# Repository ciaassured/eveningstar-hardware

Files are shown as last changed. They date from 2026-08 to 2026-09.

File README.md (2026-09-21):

# EveningStar Hardware

<p align="center">
  Rotating 3D render of the EveningStar PCB
</p>

EveningStar is a gateway between a Morningstar MeterBus network and a standard Ethernet/IP network. It connects to the MeterBus port of a Morningstar solar charge controller or other compatible device, making the bus accessible over Ethernet for monitoring, automation, and control.

The hardware is built around an ESP32-C6 and divided into two galvanically isolated sections:

* A MeterBus interface, powered from the connected Morningstar device.
* An ESP32 and Ethernet interface, powered from its own DC input.

This isolation keeps the MeterBus network and the Morningstar device's ground separate from the rest of the system, which prevents ground loops through the MeterBus cable and stops fault currents from flowing across it. The ESP32 side can be powered from the same battery system as the charge controller or from a separate supply, even when the two operate at different voltages.

MeterBus communication is half-duplex and open-drain. The interface includes a Schmitt-trigger receive path and transient-voltage-suppression clamps to improve reliability when cables are routed through electrically noisy environments.

## Specifications

| | |
| --- | --- |
| Processor | ESP32-C6-WROOM-1-N8 module: Wi-Fi 6, Bluetooth LE, and IEEE 802.15.4, with 8 MB flash and an on-board antenna |
| Storage | 256 MB SPI NAND flash (GD5F2GM7) |
| Real-time clock | 32.768 kHz crystal |
| Ethernet | 10/100 Mbit/s, WIZnet W5500 with a hardware TCP/IP stack, RJ45 jack with integrated magnetics |
| MeterBus | RJ11 (6P6C) jack to the Morningstar MeterBus port |
| USB | USB-C to the ESP32-C6's native USB, for flashing, a serial console, and JTAG debugging; it does not power the board |
| Debug | Unpopulated 2.54 mm 2×3 header with serial, reset, and boot pins |
| Power input | 8–40 V DC through a 3.81 mm pluggable terminal block, ESP32 side |
| MeterBus supply | Powered by the Morningstar device through the MeterBus port, up to the 15.5 V Morningstar specifies, MeterBus side |
| Isolation | ISO6721 digital isolator between the two sides, rated 3000 V rms withstand and 450 V rms working voltage (basic isolation, UL 1577); only data crosses it |
| Operating temperature | −30 °C to +85 °C, from component ratings |
| Board size | 81.2 × 71.6 mm |

## Protection

* **Power input:** a 1 A fuse, a series Schottky diode against reverse polarity, and a 40 V TVS diode that clamps surges. The TVS diode sets the 40 V upper limit, well within the 80 V rating of the LMR38020S converter behind it.
* **Brown-out:** the ESP32 is held in reset until the converter reports that the 3.3 V rail is in regulation.
* **MeterBus:** galvanic isolation, since the MeterBus side is powered by the Morningstar device and shares no power or ground with the rest of the board. Its supply has a series Schottky diode against reverse polarity and a 17 V TVS diode, and the data line has a TVS clamp for positive and negative spikes.
* **USB:** ESD protection on the data lines. VBUS is not connected to any power rail, so the board cannot draw power from USB or feed power back into it.
* **Ethernet:** the jack's integrated magnetics transformer-couple the data pairs, and its shield is connected to ground only through a 1 nF, 2 kV capacitor, so the Ethernet cable carries no DC ground current.

The ratings above come from component datasheets. The board has not been independently tested or certified for isolation, surge immunity, or its temperature range.

## Installation

* **Power:** connect 8–40 V DC to the terminal block, observing the + and − markings on the bottom of the board. Add a Fuse the positive supply with a 1 A fuse close to the power source, and use wiring rated to carry at least 1 A continuously. This fuse protects the wiring in case of a short circuit. Choose a fuse that is appropriately rated for the system's voltages and currents.
* **MeterBus:** connect the RJ11 jack to the Morningstar device's MeterBus port using a standard straight through cable. The MeterBus side takes its power from that port. The outer two pins on each side of the 6P6C connector are shorted which means it is possible to use a four pin cable, but six pin is recommended.
* **Ethernet:** connect a standard Ethernet cable. The board is not powered over Ethernet. Note that this device does not support Auto-MDIX so a crossover cable may be needed in some cases if the other device also doesn't support auto Auto-MDIX.

> [!WARNING]
> Do not leave USB connected while the system is in service. USB ground is connected directly to the power input's negative terminal, so a connected USB host that is grounded elsewhere creates a second ground path. Current can then flow through the board's unfused ground and the USB cable, which can damage equipment or start a fire. Use USB only for flashing or debugging, and disconnect it afterwards.

## Debugging

### USB

The USB-C port connects straight to the ESP32-C6's native USB; there is no USB-to-serial chip in between. The chip's built-in USB Serial/JTAG controller gives a serial console, flashing, and JTAG debugging over one cable. The controller is part of the chip's hardware and is supported by its ROM bootloader, so it works on a blank module with no bootloader or firmware in flash, and the chip can enter download mode over USB by itself.

Firmware can still make the USB device disappear, by reconfiguring the USB pins, disabling the controller, or entering a sleep mode. If that happens, force the chip into its ROM download mode through the debug header, as below.

Remember that USB is for flashing and debugging only; see the warning under [Installation](#installation).

### Debug header

The unpopulated 2.54 mm 2×3 header, marked DEBUG, breaks out the ESP32's first serial port and its reset and boot pins:

| Pin | Label | Signal |
| --- | --- | --- |
| 1 | RST | ESP32 reset (EN), active low |
| 2 | 3V3 | Board 3.3 V rail, through jumper J_3V3 |
| 3 | TX | ESP32 UART0 transmit; connect to the adapter's receive |
| 4 | GND | Ground |
| 5 | RX | ESP32 UART0 receive; connect to the adapter's transmit |
| 6 | BOOT | ESP32 GPIO9; held low at reset, it enters ROM download mode |

Use it to flash over serial, including the bootloader, or to recover a board whose firmware has disabled native USB: hold BOOT low while releasing RST, and the chip starts in ROM download mode. Programmers that drive both pins can do this automatically.

When using the header, power the board with an external DC supply through its normal power input and on-board converter, and remove jumper J_3V3 so that the programmer's 3.3 V cannot backfeed the converter.

If the converter's power-good signal holds the reset line low while you are trying to flash or debug through the header, remove jumper J_RST as well; it connects the power-good signal to the ESP32's reset line.

J_3V3 and J_RST are 0603 0 Ω resistors beside the header, fitted at assembly and marked on the silkscreen.

## Resources

* Schematics, board drawings, 3D models, renders, and JLCPCB production files for the current hardware revision are attached to the [latest release](https://github.com/ciaassured/eveningstar-hardware/releases/latest).
* To order assembled boards, follow [`docs/jlcpcb_order.md`](docs/jlcpcb_order.md).
* Firmware is maintained separately in the [eveningstar-firmware](https://github.com/ciaassured/eveningstar-firmware) repository.
* The KiCad project and its build, review, and fabrication workflow are documented in [`pcb/README.md`](pcb/README.md).

## Disclaimer

This project is experimental and is not affiliated with or endorsed by Morningstar Corporation.

Use it at your own risk when interfacing with battery and solar equipment.

### AI Assistance

Portions of this project were created or modified using AI-assisted tools. AI-generated suggestions may be incomplete or incorrect and must not be treated as engineering certification.

Before manufacturing or using this hardware, independently review the schematics, PCB layout, component ratings, isolation boundaries, and fabrication outputs. Appropriate electrical, thermal, safety, and regulatory testing must also be performed.

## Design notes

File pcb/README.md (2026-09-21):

# EveningStar PCB

This directory contains the KiCad project for the EveningStar PCB.

## Reproducibility Goal

The PCB should remain openable from this repository in the future, even if
external KiCad libraries, plugin indexes, vendor APIs, or downloaded data
sources disappear or change shape.

The rule of thumb is:

- Project-specific symbols, footprints, and 3D models should be committed under
  `pcb/lib`.
- Third-party libraries that are used by the board should be vendored into this
  repository, not referenced through a local KiCad plugin path.
- External tools are acceptable when they are sufficiently pinned and
  recoverable. KiCad itself is provided through the root Nix flake and locked by
  `flake.lock`.
- KiCad stock symbols are referenced through `KICAD_SYMBOL_DIR`, which is set by
  the Nix tooling to the flake-pinned KiCad package.

If a part needs local customization, copy the symbol, footprint, or model into a
project-owned library and reference that copy.

## Nix Workflow

The root flake owns the lock file and imports the PCB-specific Nix module from
`pcb/nix`. Use the flake from the repository root.

Open a shell with the pinned KiCad version:

```sh
nix develop
```

The dev shell includes KiCad plus the project helper scripts. Inside the shell,
the scripts are available as `eveningstar-*` commands.

Entering the development shell installs or updates the repo's pre-commit hook
for the current clone. It can also be installed explicitly from the shell:

```sh
lefthook install
```

Git does not automatically trust and execute hooks from cloned repositories.
Entering `nix develop` is the developer's explicit trust step: the shell uses
the Nix-provided Lefthook to sync `.git/hooks`, so Nix remains the only tooling
dependency. Lefthook then runs the same Nix-backed check suite used by CI.

## Checks

Run every automated check:

```sh
nix run .#checks
# or, inside nix develop:
eveningstar-checks
```

The aggregate command runs all checks even if an earlier one fails, then exits
non-zero if any failed. It is the entry point used by Lefthook and GitHub
Actions.

The individual checks remain available for diagnosing a failure.

### ERC and DRC

Run KiCad ERC and DRC, including warnings:

```sh
nix run .#drc
# or, inside nix develop:
eveningstar-drc
```

This writes `reports/erc.rpt` and `reports/drc.rpt`, prints both reports, and
exits non-zero if ERC or DRC reports violations.

### Repo-local KiCad references

Check for references to local, non-repo KiCad libraries or model paths:

```sh
nix run .#kicad-locality
# or, inside nix develop:
eveningstar-kicad-locality
```

This fails on absolute paths, KiCad third-party plugin variables, missing
repo-local 3D models, footprint library table entries outside `${KIPRJMOD}`, and
symbol library table entries outside `${KIPRJMOD}` or pinned `KICAD_SYMBOL_DIR`.

### Saved copper-zone fills

Check that every copper zone contains saved fill data on each of its layers:

```sh
nix run .#zones-filled
# or, inside nix develop:
eveningstar-zones-filled
```

After any board edit that can affect copper geometry, open the board in the
pinned KiCad PCB Editor, press <kbd>B</kbd> to refill all zones, and save before
committing. Production plotting uses the fills stored in the board, so this is
required even if DRC passes. The automated check detects absent saved fills; it
cannot prove that existing fills are current for the latest board edits.

### Vendored subtree drift

Check that the vendored JLCPCB subtree has not been edited directly:

```sh
nix run .#subtree-drift
# or, inside nix develop:
eveningstar-subtree-drift
```

This verifies `pcb/lib/JLCPCB-Kicad-Library` still matches the recorded subtree
squash commit and rejects uncommitted changes under that subtree.

## Publish Tools

Publish tools generate the complete artifact set for one hardware revision. They
are available through Nix, but are intentionally not run by Lefthook or CI.

Generate publish artifacts for the current checkout:

```sh
nix build --max-jobs auto .#publish
# or, to also link the result at reports/publish:
nix run .#publish
# inside nix develop:
eveningstar-publish
```

The output is exactly the set of GitHub release assets, in one flat directory
because releases hold no folders:

| File | Contents |
| --- | --- |
| `EveningStar-gerbers.zip` | Gerber and drill files for JLCPCB |
| `EveningStar-bom.csv` | JLCPCB bill of materials |
| `EveningStar-cpl.csv` | JLCPCB component placement list |
| `EveningStar-netlist.ipc` | IPC-D-356 netlist for electrical test |
| `EveningStar-schematic.pdf`  | every schematic sheet |
| `EveningStar-board.pdf` | composite front and back views, then each layer |
| `EveningStar-step.zip` | STEP model of the assembled board, for enclosure CAD  |
| `EveningStar.glb` | browser-optimized 3D model |
| `EveningStar-render-*.png` | top, bottom, front, back, and isometric renders |
| `EveningStar-turntable.webp` | the [turntable animation](#turntable-animation) |
| `SHA256SUMS` | checksums of every other file |

Names carry no version, so `releases/latest/download/<name>` always links the
newest board, and the output depends only on the source rather than on the tag
it is released under. The production files are the `.#production` payload, which
uses the same names; the Toolkit's `designators.csv` is left out of both because
it only repeats the BOM. The per-sheet and per-layer SVGs are review artifacts
rather than release assets, built by `nix run .#review`.

`nix build` exposes the Nix store output through `result`; the command form also links that immutable output at
`reports/publish`. Because this is a derivation of the filtered PCB source and
pinned publishing tools, unchanged outputs are reused from the local Nix store
and can be shared through the configured Cachix cache. Release metadata and
changelog generation can be added to this same artifact contract without
changing the review workflow.

Generate only the JLCPCB production payload:

```sh
nix build .#production
# or, to also link the result at reports/production:
nix run .#production
# inside nix develop:
eveningstar-production
```

The production payload contains the Gerber/drill archive, BOM, placement list,
and IPC-D-356 netlist, under the same names as the GitHub release. Its settings
pin the Fabrication Toolkit 5.3.1 JLCPCB placement translations used for V1. The
build runs DRC and schematic-parity validation, then plots the zone fills
committed in the KiCad board without refilling them. Fill and save zones in the
pinned KiCad editor after relevant design changes; plotting the reviewed stored
fills avoids nondeterministic polygon decomposition between independent KiCad
processes. Project-specific corrections live as hidden `FT Rotation Offset`
fields on the affected KiCad footprints; update them only after checking
component pin 1 orientation against the datasheet and assembly preview. The
Toolkit's built-in rotations match footprint names by pattern, such as
`^SOT-23`, and are meant for KiCad's standard footprints, so EasyEDA-named
footprints that happen to match, such as D7's
`SOT-23-3_L3.0-W1.7-P0.95-LS2.9-BR`, carry a 180° offset that cancels them.
Through-hole parts are placed at the centre of their pads unless `FT Origin` is
`Anchor`, which RJ2 uses because JLCPCB's model for it sits on the footprint
anchor. U1's SOT-89 counts as through-hole because its tab has plated holes, so
it needs the same. Generated timestamps, ZIP entry metadata, permissions, and
file order are normalized for reproducible builds. The Toolkit source revision
is pinned by the root `flake.lock` alongside KiCad and the rest of the
toolchain. KiCad provides the underlying fabrication exporters; the pinned
Toolkit is retained for its JLCPCB-specific component-origin and rotation
translations and for compatibility with the production process used for the
original board.

Production files are build artifacts and are not committed. Local output is
ignored under `pcb/production` and `reports`; published manufacturing files
belong in the GitHub release for the exact source tag that produced them. The
original as-ordered files remain available from the historical `v1.0.0` tag.

To force a fresh build and have Nix compare it with the existing store output:

```sh
nix build .#production --rebuild
```

The aggregate is assembled from independent schematic-document, PCB-document,
plan-render, side-render, isometric-render, turntable-render, GLB, STEP, and
production derivations. Nix can schedule those components in parallel and reuse
them individually. They are also directly inspectable with commands such as
`nix build .#render-plan` or `nix build .#model-step`, without exposing
additional imperative applications.

### Turntable animation

Build the looping turntable animation used to showcase the board:

```sh
nix build --max-jobs auto .#render-turntable
```

That leaves the usual `result` symlink, which is a garbage-collection root, so
the animation is at `result/EveningStar-turntable.webp`. It is not committed:
`.#publish` carries it as `EveningStar-turntable.webp`, and
`nix run .#release` attaches it to the GitHub release, which the top-level
`README.md` embeds through the `releases/latest/download/` alias so the link
survives future releases untouched. Print the store path with
`nix build --print-out-paths` if something needs to consume the output without
relying on `result`.

The render is a chain of derivations of the filtered PCB source and the pinned
toolchain, each reused from the store, and shareable through Cachix, while its
inputs are unchanged:

| Package | Produces |
| --- | --- |
| `.#board-glb` | the board as fitted, as an uncompressed kicad-cli GLB |
| `.#turntable-frames` | one PNG per frame, rendered from it by Cycles |
| `.#render-turntable` | `EveningStar-turntable.webp`, encoded from the frames |

`.#model-glb`, the browser model in the release, is `.#board-glb` compressed
with `gltfpack`. Changing the render script re-renders the frames without
re-exporting the board, and changing the encoding re-encodes without rendering.

The board stands upright on its bottom edge, the way round it is drawn, leans
20°, and rides a turntable in front of a level, still camera, sweeping front
face to edge-on sliver to back face. The lean belongs to the board rather than
to the viewer, so it swings round with the spin: the component side is seen from
above, the bare copper side from below half a turn later, and the board rocks
from side to side through the edge-on quarters. Key, fill, and rim area lights
stay put while the board turns, so shadows sweep across it as they would in a
studio. The animation is 180 frames of a full revolution at a 33 ms frame delay,
so it runs at 30 fps and takes just under six seconds to come round. It is
encoded as an animated WebP with an alpha channel, so it sits on light and dark
README backgrounds alike.

`pcb/nix/scripts/turntable.py` runs inside Blender. Its options are the knobs:
`--tilt` (`20` reverses the lean), `--stand` to turn the board within its own
plane before it is stood up, `--frames`, `--width`, `--height`, `--fill`,
`--focal-length`, `--samples`, and `--mask-colour`. `--only` renders just the
listed frames, which is the quick way to try a change:

```sh
nix build .#board-glb
nix shell --inputs-from . nixpkgs#blender -c blender -b --factory-startup \
  --python-exit-code 1 -P pcb/nix/scripts/turntable.py -- \
  --model result/EveningStar.glb --output reports/turntable --only 0,45,90
```

At a 760x720 canvas the animation lands around 4.5 MB. The WebP settings live in
the `.#render-turntable` derivation. Quality 65 is already low enough that the
frames are visually indistinguishable from the PNGs, and method 6 took around
forty times longer than method 4 on one core for about 4% smaller output, so the
frame count and canvas size are where the remaining bytes are.

The camera distance is solved once from the geometry, so that the widest point
of the whole revolution reaches `--fill` of the canvas and the board stays the
same size in every frame. Every vertex rides a circle of radius r at height z
about the spin axis. Seen from distance D, it reaches at most r / sqrt(D² − r²)
across the frame and |z| / (D − r) up or down, each scaled by the lens, so the
maximum over the vertices bounds the continuous revolution exactly, and a
bisection on D lands it on the fill.

kicad-cli gives the board layers materials of their own, on meshes named
`<board>_soldermask`, `<board>_pad`, and so on, and the script sets those to a
coated mask in `--mask-colour`, gold pads and vias, white silkscreen, and FR4.
Component models carry only a colour through the export, so they arrive at
glTF's defaults of fully metallic and fully rough, which renders plastic as dull
metal. These models paint bare metal in light neutral colours up to pure white:
leads, terminals, the magjack and ESP32 shields, and the electrolytic's can,
some with a blue cast. The script makes those and gold-ish ones polished metal,
and the dark and strongly coloured rest plastic. Metal needs something to
mirror, so the world behind the transparent film is a studio backdrop, bright
overhead and dark underfoot. Do-not-populate parts are left out of the export.
The frames use Blender's AgX view transform with its punchy look, which keeps
the mask a deep blue and the plastics dark under studio lights.

Cycles renders on the CPU, since the build sandbox has no GPU, at 32 samples
with denoising, which came within 45 dB PSNR of 64 samples at well under two
thirds of the time. One Blender process uses every core Nix grants the build;
splitting the frames across several processes measured no faster. With a fixed
seed the frames are reproducible: two runs on the same machine render identical
pixels. On a 32-core machine the frames take about nine minutes. Blender's
closure is about 3.8 GB, fetched once from the binary cache.

The render used to be done by `kicad-cli pcb render`, which cannot keep lights
still while the board turns. It builds its own lights fixed to the board and
ignores any in its settings, so cast shadows stayed glued to the board while its
view-following camera light, which casts none, moved the shading. Its framing
also took probe renders, since it fits each image to the canvas individually and
zooms in perspective by moving the camera.

Because the animation is hosted rather than committed, a rebuild does not
disturb anything that is already published. Each release attaches the animation
rendered from its own source, so the README always shows the latest released
board.

Including the animation in `.#publish` adds about nine minutes to a
publish whenever the board has changed, more on machines with fewer cores. It is
not part of the review artifacts, so `nix run .#review` does not render it.

### Releases and hardware versioning

Release versions describe the hardware revision, not the volume or significance
of changes to the surrounding checks, rendering, review, or publishing tools.
Tooling-only changes do not normally require a hardware release.

- Increment the major version for an incompatible electrical, mechanical, or
  external-interface change.
- Increment the minor version for a backwards-compatible hardware capability or
  intentional circuit, component, or layout revision.
- Increment the patch version for corrections that preserve the intended
  circuit and interfaces, including fabrication-data, copper, keepout, and
  silkscreen fixes.

`v1.0.0` is a historical source tag and intentionally has no GitHub Release.
`v1.0.1` is the first release produced with the pinned, reproducible production
and publishing pipeline.

To prepare a release, first merge all intended changes to `main`, refill and
save copper zones after relevant board edits, and create a Markdown release
notes file. Review the changes and choose the version based primarily on the
schematics, board, and production outputs since the previous hardware tag:

```sh
nix run .#review -- v1.0.0 main
nix run .#release -- --dry-run v1.0.1 /path/to/release-notes.md
```

Inspect the rendered comparison and the staged assets under
`reports/release/v1.0.1/`. The dry run executes the complete checks and publish
build but does not create a tag or GitHub Release. When the result is ready to
publish, run:

```sh
nix run .#release -- v1.0.1 /path/to/release-notes.md
```

The release command requires a clean checkout of the latest `origin/main`,
rejects conflicting tags or releases, runs `nix run .#checks`, and builds the
full publish output locally. It checks that output against its `SHA256SUMS` and
stages it unchanged as the release assets; then it creates and pushes an
annotated tag and creates the GitHub Release. If GitHub release creation fails after the tag is pushed, correct the
problem and rerun the same command; an existing tag is accepted only when it
identifies the same `main` commit.

## Review Tools

Review tools generate artifacts for a human to inspect or compare. They are
available through Nix, but are intentionally not run by Lefthook or CI.

Generate a comparison from a pull request number or URL:

```sh
nix run .#review -- 31
# equivalent explicit form:
nix run .#review -- --pr 31
# URLs also work:
nix run .#review -- https://github.com/ciaassured/eveningstar-hardware/pull/31
# or, inside nix develop:
eveningstar-review 31
```

Compare any two locally available commits, branches, or tags by listing the
destination revision first and the source revision second:

```sh
nix run .#review -- v0.2.0 v0.3.0
nix run .#review -- main feature/new-layout
nix run .#review -- 2c5bf31 96e61e4
```

Compare a revision with the current working tree using `--worktree`. This
includes staged, unstaged, untracked, and deleted files, but excludes files
ignored by Git:

```sh
nix run .#review -- main --worktree
# HEAD is the default destination revision:
nix run .#review -- --worktree
```

For pull requests, the command resolves the exact source and destination
commits recorded by GitHub without changing or depending on the checkout. Git
revision comparisons archive the exact requested trees, while worktree
comparisons create an isolated temporary snapshot without switching branches or
modifying local files. Nix realizes the same publish derivation for either form.
Cached artifact sets are reused, then linked under
`reports/review` and compared through their browser-viewable SVG, PNG, and GLB
outputs. It serves the comparison on an ephemeral `127.0.0.1` port and prints
the URL; press Ctrl+C when the review is finished.
It also opens the URL in the default browser when a desktop opener is available;
the foreground server exits when interrupted and does not remain orphaned.
The view picker covers native vector schematic and board views, deterministic
KiCad 3D renders, and the interactive Three.js board model. Every view supports
overlay/reveal, side-by-side, pixel-difference, and highlighted-change modes.
Documents can be panned and zoomed without rasterizing SVGs; side-by-side
navigation can optionally be synchronized. Use <kbd>←</kbd> and <kbd>→</kbd> to
change view, <kbd>↑</kbd> and <kbd>↓</kbd> to change comparison mode, and
<kbd>[</kbd> and <kbd>]</kbd> to move through the current view's pages, layers,
images, or presets. Pull-request comparisons use `gh` for metadata and Git to
fetch missing commit objects; both are provided by Nix.

Generate the report without starting the local server:

```sh
nix run .#review -- --no-serve 31
nix run .#review -- --no-serve main --worktree
```

Because the review tool comes from the current checkout while the hardware
inputs come from the requested snapshots, a feature branch can test changes to
the review tooling against an existing PR or pair of revisions.

Artifacts are written under `reports/`.

## CI Checks

Pull requests to `main` run `.github/workflows/checks.yml`.

The workflow:

- Installs Nix.
- Optionally configures Cachix.
- Runs `nix run .#checks`, the same aggregate command used by Lefthook.
- Uploads ERC and DRC reports when they are generated.

The aggregate command attempts every check, so a failure in an earlier check
does not prevent ERC/DRC reports from being generated and uploaded.

## Library Layout

Vendored and project-owned libraries live under `pcb/lib`.

```text
pcb/lib/
  custom/
    custom_symbols.kicad_sym
  EasyEDA/
    EasyEDA.kicad_sym
    EasyEDA.pretty/
    EasyEDA.3dshapes/
  JLCPCB-Kicad-Library/
    symbols/
    footprints/
    3dmodels/
```

The KiCad library nicknames are kept stable in `sym-lib-table` and
`fp-lib-table`, so schematic references like `EasyEDA:...`,
`custom_symbols:...`, and `PCM_JLCPCB:...` remain readable.

## Development Plugins And Sources

This board has used external KiCad plugins and data sources during development:

- [ImpartGUI](https://github.com/Steffen-W/Import-LIB-KiCad-Plugin)
- [JLCPCB Fabrication Toolkit](https://github.com/bennymeg/Fabrication-Toolkit)
- [JLCPCB-Kicad-Library](https://github.com/CDFER/JLCPCB-Kicad-Library)

Those tools are useful if you are actively adding or updating parts, generating
fabrication outputs, or syncing vendor metadata. Someone working on the board
will probably want them installed in their interactive KiCad setup.

They should not be required just to open, check, or review the project. Any
symbols, footprints, or 3D models required by the board should be present in
this repository, and KiCad itself should be obtained through Nix.

## Adding Parts

When adding a part from a plugin or external source:

1. Add or copy the required symbol, footprint, and 3D model into `pcb/lib`.
2. Reference files through `${KIPRJMOD}/lib/...`, not through
   `${KICAD*_3RD_PARTY}`, absolute paths, or plugin cache paths.
3. Run `nix run .#checks`.

For the vendored JLCPCB subtree, do not edit files in
`pcb/lib/JLCPCB-Kicad-Library` directly. Update the subtree as a subtree, or
copy the asset into a project-owned library before customizing it.

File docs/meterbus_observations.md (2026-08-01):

# MeterBus Observations

This document describes observations and measurements of the Morningstar MeterBus interface.

Morningstar MeterBus is a single-wire open-collector style serial bus exposed on an RJ11 connector.

## Power Supply

The Morningstar controllers supply some power via the RJ11 interface.

### Voltage

When testing the supply from a ProStar MPPT controller, the voltage appeared to be regulated to a maximum of 11.9VDC, but fell as the battery voltage dropped below 12.9VDC. Similar testing with a SunSaver MPPT controller seemed to show the output was regulated to about 14VDC. Battery voltage for the testing ranged from 5VDC up to and above 24VDC.

These observations fit within the range of 8VDC - 15.5VDC specified by Morningstar in [`Meterbus Adapter Instructions`](./docs/operation-manual-pc-meterbus-adapter-en.pdf).

All power pins on the RJ11 connector appear to be bridged together, as do the ground pins.

### Current

Observed load-test results for the nominal 12 V supply:

| Load resistor | Measured voltage | Calculated current |
| ---: | ---: | ---: |
|  Open circuit | 12.4 V | 0 mA |
| 150 Ω | 8.4 V | 56 mA |
| 67 Ω | 4.2 V | 62.7 mA |
| 33 Ω | 2.4 V | 72.7 mA |
| 0 Ω | 0 V | 13 mA |

Overall, the supply voltage sags heavily under load, while current rises into roughly the **55–75 mA** range over these tests.

## MeterBus

Measurements of the bus pin on both ProStar MPPT and SunSaver MPPT controllers show that the bus idles high at about 7.5VDC, and is pulled down to 0VDC when the controller transmits. The bus is a half-duplex serial line running at 9600 baud, with 8 data bits, 2 stop bits and no parity. 

The bus is weakly pulled up, and has a short circuit current to ground of about 700-800uA for both controllers

If we assume that the bus is pulled to an internal rail of 7.5VDC with a resistor, Ohms Law `7.5V/850uA=10kOhm` says the internal resistor is 10kOhms.

### Low Level Threshold

In order to figure out what bus voltage the controllers consider as a logic LOW, we tested several values of **R** in the test circuit pictured below while probing the bus with an oscilloscope.

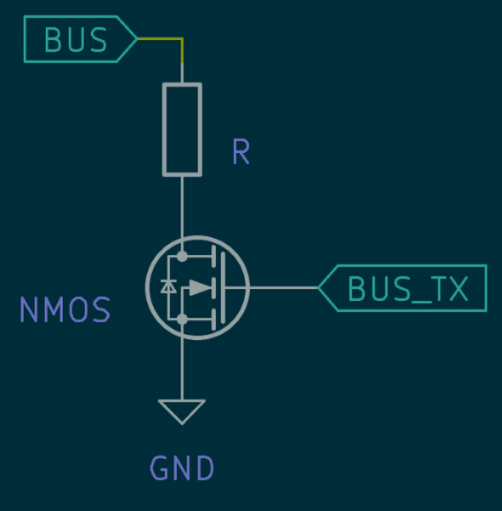
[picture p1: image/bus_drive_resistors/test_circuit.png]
Bus test circuit


The oscilloscope traces can be found in [this folder](/image/bus_drive_resistors). The first block of data in the traces is the test circuit requesting the controller voltage over modbus, and the second block is the controller responding. Traces only show the first block of data when the controller did not respond.

The results showed that the controller stopped responding consistently at around 2.733kOhm, when the LOW level was around 1.3VDC.

The observed voltages also roughly match a voltage divider with the top resistor being 10kOhms, which seems to confirm that the controller probably has a 10kOhm pullup resistor internally.

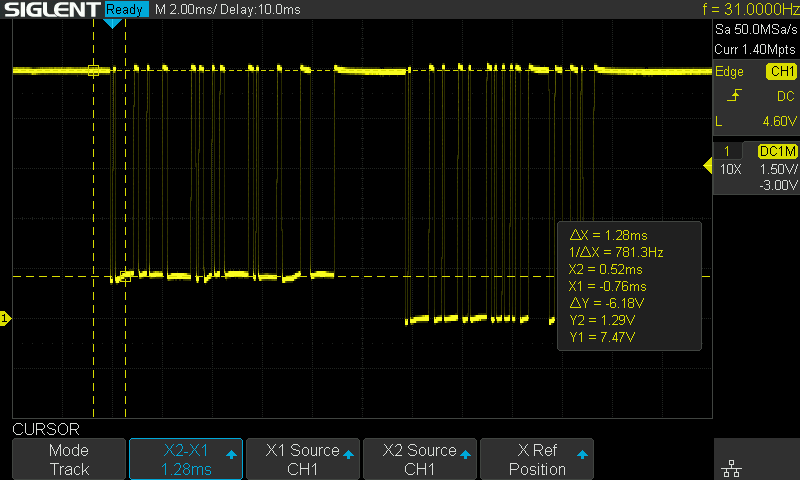
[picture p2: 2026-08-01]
assets/bus_drive_resistors/2700ohm.png

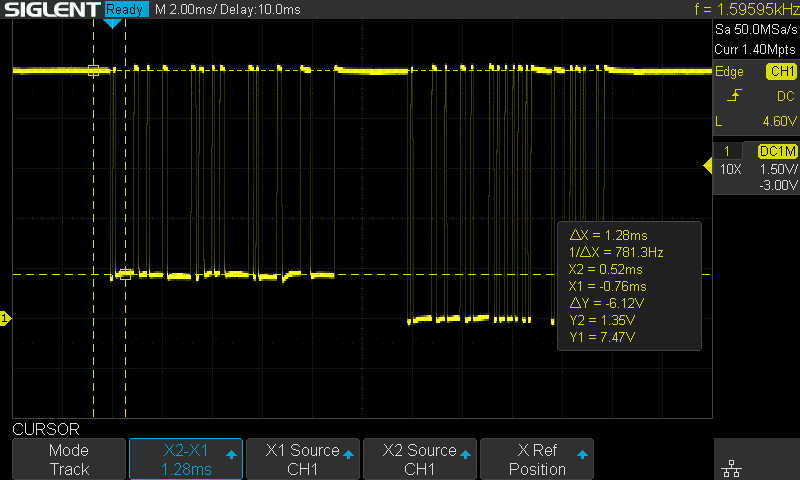
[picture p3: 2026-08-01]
assets/bus_drive_resistors/2733ohm-1.png

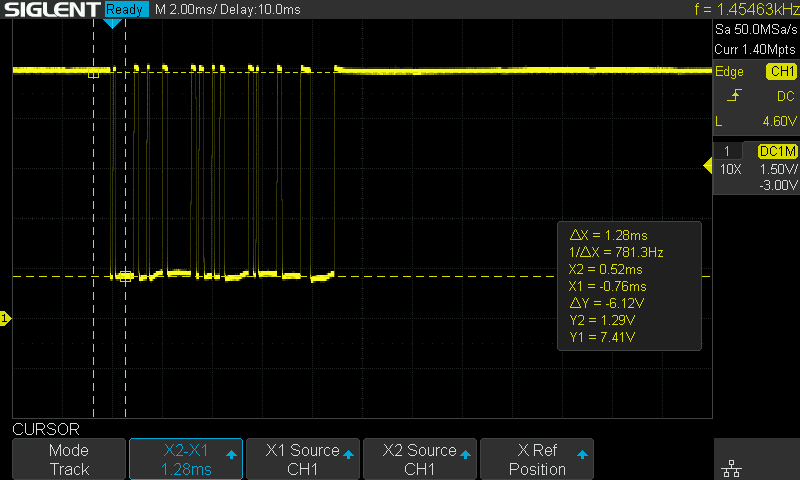
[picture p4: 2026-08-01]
assets/bus_drive_resistors/2733ohm-2.png

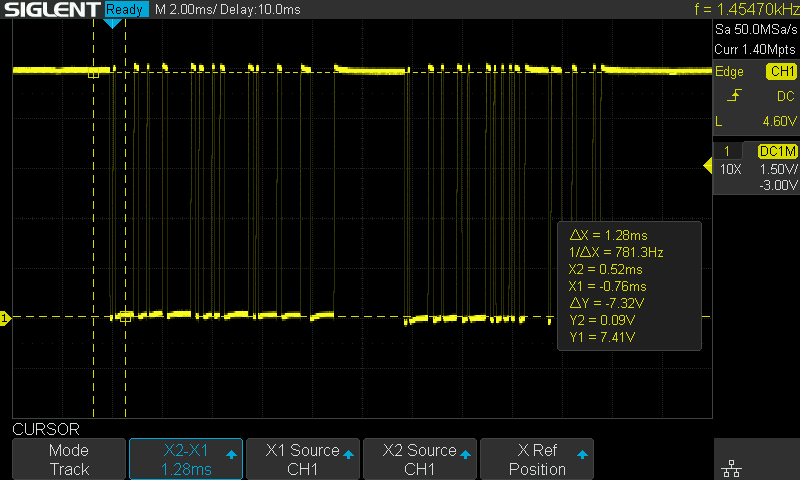
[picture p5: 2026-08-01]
assets/bus_drive_resistors/330ohm.png

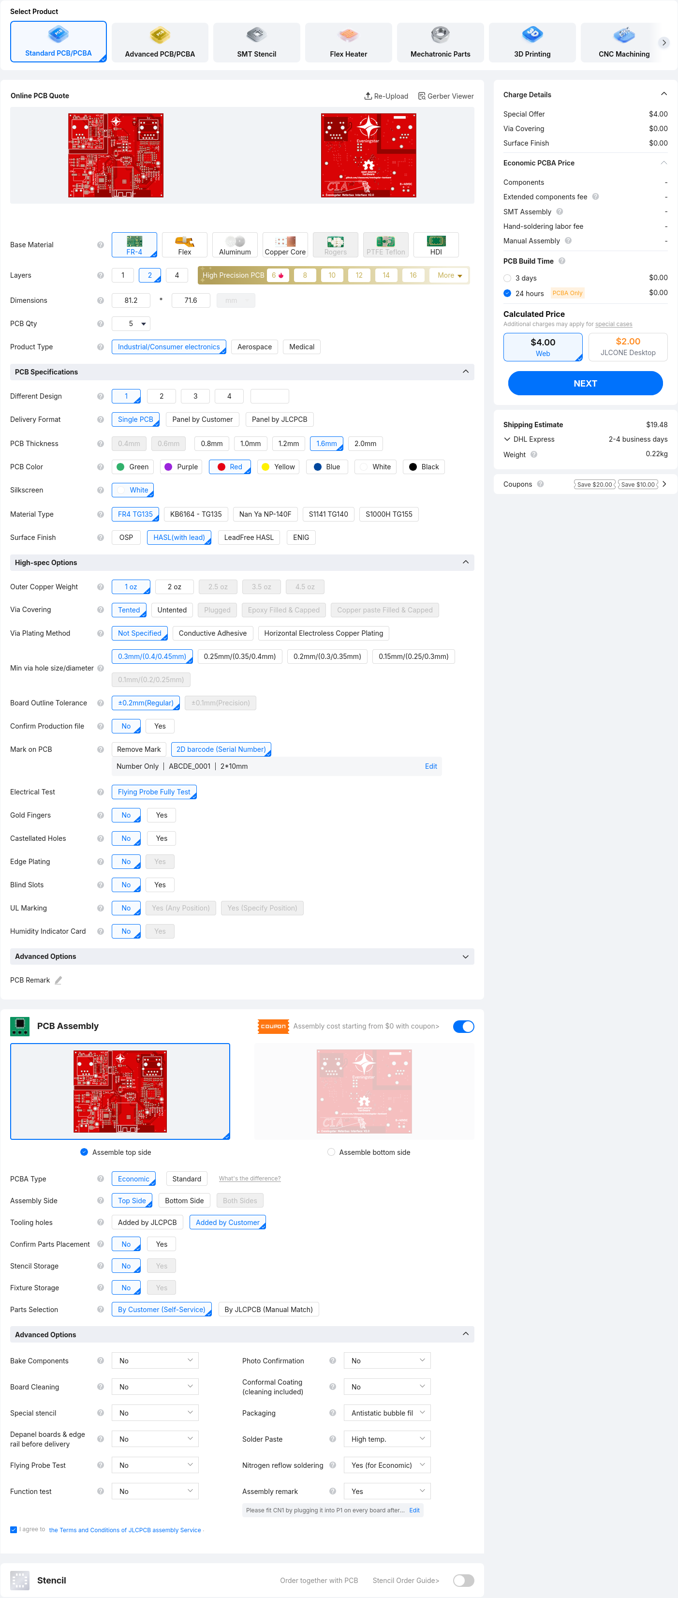
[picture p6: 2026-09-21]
assets/jlcpcb_quote_screenshot.png

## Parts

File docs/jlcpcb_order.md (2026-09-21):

# Ordering PCB from JLCPCB

This guide includes instructions on how to order an assembled PCB from [JLCPCB](https://jlcpcb.com)

## Production files

Download the production files from the latest GitHub release:

- [`EveningStar-gerbers.zip`](https://github.com/ciaassured/eveningstar-hardware/releases/latest/download/EveningStar-gerbers.zip)
- [`EveningStar-bom.csv`](https://github.com/ciaassured/eveningstar-hardware/releases/latest/download/EveningStar-bom.csv)
- [`EveningStar-cpl.csv`](https://github.com/ciaassured/eveningstar-hardware/releases/latest/download/EveningStar-cpl.csv)

To order an older hardware version, take the files from that version's release
instead. Releases up to v1.0.1 name them `EveningStar.zip`, `bom.csv`, and
`positions.csv`.

Alternatively, build them from a checkout of the tag being ordered by running
the following command from the repository root:

```sh
nix build .#production
```

This leaves the same files under `result/`. Do not use manufacturing files from
a different tag or an unreviewed working tree.

## Instant Quote

1. The first step is to visit the [JLCPCB quote page](https://cart.jlcpcb.com/quote) or visit the home-page and click **Get Instant Quote**.

2. Sign In. You must sign in later anyway, and if you don't sign in now the form sometimes glitches out and changes options.

3. Select **Add gerber file** and upload `EveningStar-gerbers.zip`.

4. Select the number of PCBs you want to order.

5. Select desired PCB colour (Be aware that this increases lead-time).

6. Update **Mark on PCB** to **2D barcode (Serial Number)**.

   1. Update **Printing** to **Number Only**.

   2. Update **2D Barcode Position** to **Specify Position**.

   3. Click **Submit**.

7. Enable PCB Assembly.

8. Update **Tooling holes** to **Added by Customer**

9. Update **Assembly remark** to **Yes**

   1. Enter the following remark

   ```plain
   Please fit CN1 by plugging it into P1 on every board after soldering.

   CN1 is the plug half of the pluggable terminal block (LCSC C8466, KANGNEX WJ15EDGK-3.81-02P-14-00A) and mates with the soldered header P1 (LCSC C8387, WJ15EDGRC-3.81-2P). CN1 is not soldered, so it is in the BOM but has no entry in the CPL file.

   Please insert it fully.
   ```

10. Select desired lead-time and shipping options on the right-hand side-bar.

11. Review options and compare with this [screenshot](/assets/jlcpcb_quote_screenshot.png).

12. Click **Next**.

## Assembly Parts

At this point you should be looking at a render of the PCB with no parts.

1. Check that both the Top and Bottom sides look good.

> [!NOTE]
> The bottom layer of the PCB appears backwards because the render doesn't flip it. This is fine, it will come out the right way in real life.

2. Click **NEXT**.

3. Click **Add BOM File** and upload `EveningStar-bom.csv`.

4. Click **Add CPL File** and upload `EveningStar-cpl.csv`.

5. Click **Process BOM & CPL**.

> [!NOTE]
> JLCPCB warns about CN1:
>
> ```plain
> The below parts won't be assembled due to data missing.
> CN1 designator don't exist in the CPL file.
> ```
>
> This is expected. CN1 is the plug half of the pluggable terminal block. It
> is not soldered, so it has no placement in the CPL file, and the assembly
> remark asks JLCPCB to plug it into P1 instead.
>
> Ignore the warning and continue.

6. At this point you should see a list of all the parts and how much they cost.
It's important that all parts are selected in the right hand column otherwise they will be missing when you get your board.

If parts are missing un unavailable, substitutes must be found.

> [!NOTE]
> Extended parts cost much more than Basic parts because there's a loading fee for each extended part. This is not really something to worry about at this stage, but should be considered when updating the board design.

7. Click **NEXT**.

8. The component placement screen should show you a 3D render of the board with the parts populated. Make sure to have a look and check that components things look like they're in the right place, and it's also a good idea to check that the components are rotated correctly by checking the pads on the board match the component pads, and any corner indicators (usually small circle) match on the component and the board.

9. Click **NEXT**.

10. Select something for the product decription. I used **Sensor\Controller\Precision Instrument > Temperature Sensor**.

10. Click **SAVE TO CART**.

11. The rest of the process should be reasonably self explanatory.

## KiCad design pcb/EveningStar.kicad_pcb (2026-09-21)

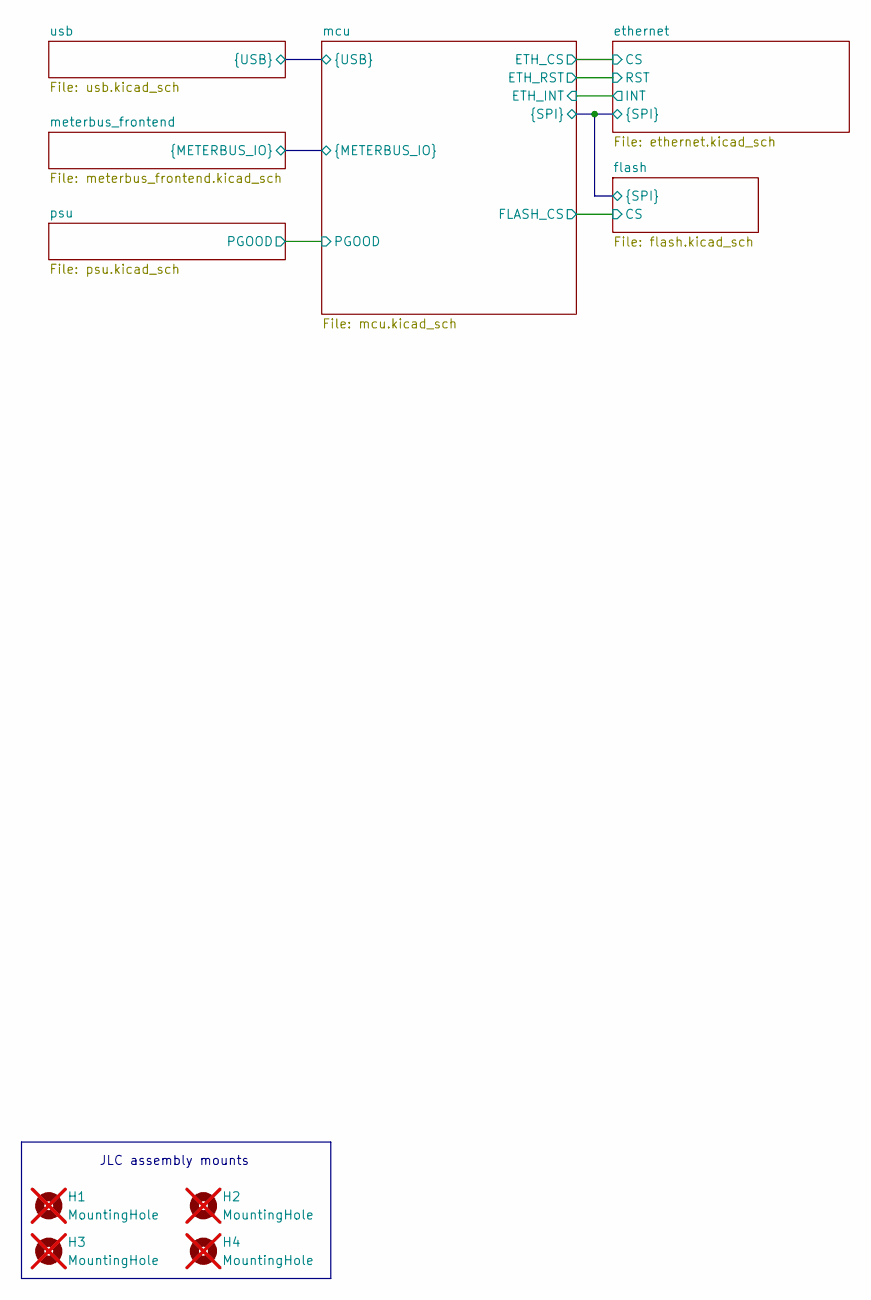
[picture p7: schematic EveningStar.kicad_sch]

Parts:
H1, H2, H3, H4: MountingHole; JLC_PCBA_Tooling_Mount; not fitted

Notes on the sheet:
JLC assembly mounts

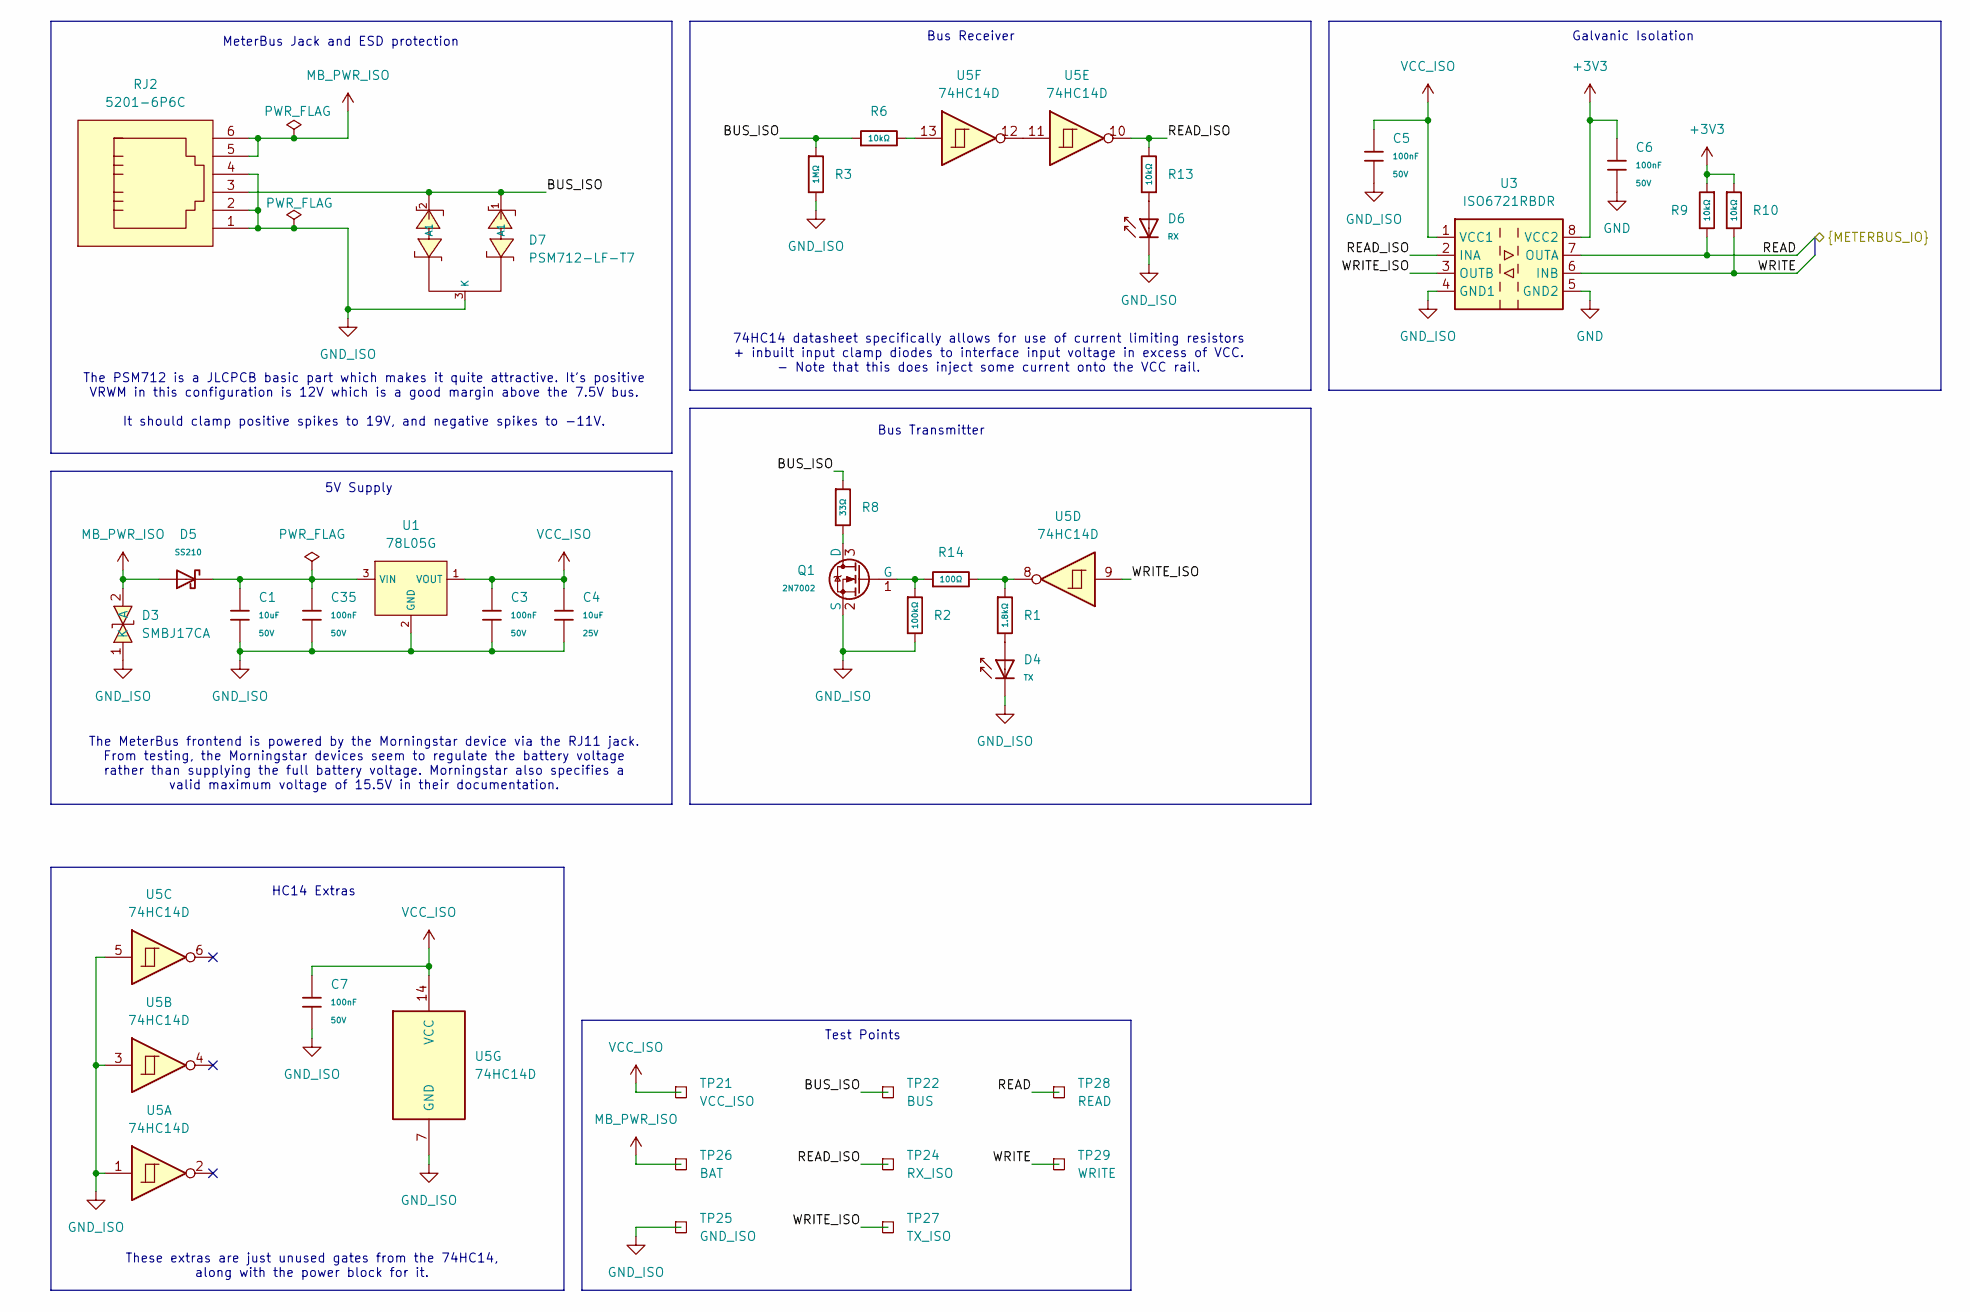
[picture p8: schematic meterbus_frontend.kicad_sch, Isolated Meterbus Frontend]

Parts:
C1: 10uF; C_1206; Voltage Rated 50V; Tolerance ±10%; Part CL31A106KBHNNNE; LCSC C13585
C3, C5, C6, C7, C35: 100nF; C_0603; Voltage Rated 50V; Tolerance ±10%; Part CC0603KRX7R9BB104; LCSC C14663
C4: 10uF; C_0603; Voltage Rated 25V; Tolerance ±20%; Part CL10A106MA8NRNC; LCSC C96446
D3: SMBJ17CA; SMB_L4.3-W3.6-LS5.4-BI; MPN SMBJ17CA; LCSC Part C3720411
D4: TX; D_0805; Forward Voltage (VF) 1.6V~2.6V; Part NCD0805R1; LCSC C84256
D5: SS210; D_SMA; Forward Voltage (Vf@If) 850mV@2A; Reverse Voltage (Vr) 100V; Part SS210; LCSC C14996
D6: RX; D_0805; Part KT-0805G; LCSC C2297
D7: PSM712-LF-T7; SOT-23-3_L3.0-W1.7-P0.95-LS2.9-BR; Breakdown Voltage 13.3V; Part PSM712-LF-T7; LCSC C32677
Q1: 2N7002; Q_SOT-23; Part 2N7002; LCSC C8545
R1: 1.8kΩ; R_0603; Overload Voltage (Max) 75V; Tolerance ±1%; Part 0603WAF1801T5E; LCSC C4177
R2: 100kΩ; R_0603; Overload Voltage (Max) 75V; Tolerance ±1%; Part 0603WAF1003T5E; LCSC C25803
R3: 1MΩ; R_0603; Overload Voltage (Max) 75V; Tolerance ±1%; Part 0603WAF1004T5E; LCSC C22935
R6, R9, R10, R13: 10kΩ; R_0603; Overload Voltage (Max) 75V; Tolerance ±1%; Part 0603WAF1002T5E; LCSC C25804
R8: 33Ω; R_0603; Overload Voltage (Max) 75V; Tolerance ±1%; Part 0603WAF330JT5E; LCSC C23140
R14: 100Ω; R_0603; Overload Voltage (Max) 75V; Tolerance ±1%; Part 0603WAF1000T5E; LCSC C22775
RJ2: 5201-6P6C; RJ45-TH_RRCH-5201-6P6C; MPN 5201-660111; LCSC Part C3097711
TP21: VCC_ISO; TestPoint_Pad_D1.0mm
TP22: BUS; TestPoint_Pad_D1.0mm
TP24: RX_ISO; TestPoint_Pad_D1.0mm
TP25: GND_ISO; TestPoint_Plated_Hole_D2.0mm
TP26: BAT; TestPoint_Plated_Hole_D2.0mm
TP27: TX_ISO; TestPoint_Pad_D1.0mm
TP28: READ; TestPoint_Pad_D1.0mm
TP29: WRITE; TestPoint_Pad_D1.0mm
U1: 78L05G; SOT-89-3_L4.5-W2.5-P1.50-LS4.2-BR; Output Voltage 5V; Dropout Voltage 1.7V@(40mA); Part 78L05G-AB3-R; LCSC C71136
U3: ISO6721RBDR; SOP-8_L4.9-W3.9-P1.27-LS6.0-BL_ISO6721RBDR; LCSC Part C5216401
U5: 74HC14D; SOIC-14_L8.7-W3.9-P1.27-LS6.0-BL; LCSC C5605

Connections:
+3V3: C6.1, R9.1, R10.1, U3.8 (VCC2); also elsewhere on the board
/mcu/READ: R9.2, TP28.1 (1_1), U3.7 (OUTA); also elsewhere on the board
/mcu/WRITE: R10.2, TP29.1 (1_1), U3.6 (INB); also elsewhere on the board
/meterbus_frontend/BUS_ISO: D7.1 (A1), D7.2 (A1), R3.1, R6.1, R8.1, RJ2.3, TP22.1 (1_1)
/meterbus_frontend/READ_ISO: R13.2, TP24.1 (1_1), U3.2 (INA), U5.10
/meterbus_frontend/WRITE_ISO: TP27.1 (1_1), U3.3 (OUTB), U5.9
GND: C6.2, U3.5 (GND2); also elsewhere on the board
GND_ISO: C1.2, C3.2, C4.2, C5.2, C7.2, C35.2, D3.1 (K), D4.1, D6.1, D7.3 (K), Q1.2 (S), R2.2, R3.2, RJ2.1, RJ2.2, RJ2.4, TP25.1 (1_1), U1.2 (GND), U3.4 (GND1), U5.1, U5.3, U5.5, U5.7 (GND)
MB_PWR_ISO: D3.2 (A), D5.2, RJ2.5, RJ2.6, TP26.1 (1_1)
unnamed: D4.2, R1.2
unnamed: D6.2, R13.1
unnamed: Q1.3 (D), R8.2
unnamed: Q1.1 (G), R2.1, R14.1
unnamed: R1.1, R14.2, U5.8
unnamed: R6.2, U5.13
unnamed: C1.1, C35.1, D5.1, U1.3 (VIN)
unnamed: U5.11, U5.12
VCC_ISO: C3.1, C4.1, C5.1, C7.1, TP21.1 (1_1), U1.1 (VOUT), U3.1 (VCC1), U5.14 (VCC)

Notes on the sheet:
74HC14 datasheet specifically allows for use of current limiting resistors + inbuilt input clamp diodes to interface input voltage in excess of VCC. - Note that this does inject some current onto the VCC rail.
Bus Transmitter
The PSM712 is a JLCPCB basic part which makes it quite attractive. It's positive VRWM in this configuration is 12V which is a good margin above the 7.5V bus. It should clamp positive spikes to 19V, and negative spikes to -11V.
Test Points
Galvanic Isolation
These extras are just unused gates from the 74HC14, along with the power block for it.
5V Supply
HC14 Extras
The MeterBus frontend is powered by the Morningstar device via the RJ11 jack. From testing, the Morningstar devices seem to regulate the battery voltage rather than supplying the full battery voltage. Morningstar also specifies a valid maximum voltage of 15.5V in their documentation.
MeterBus Jack and ESD protection
Bus Receiver

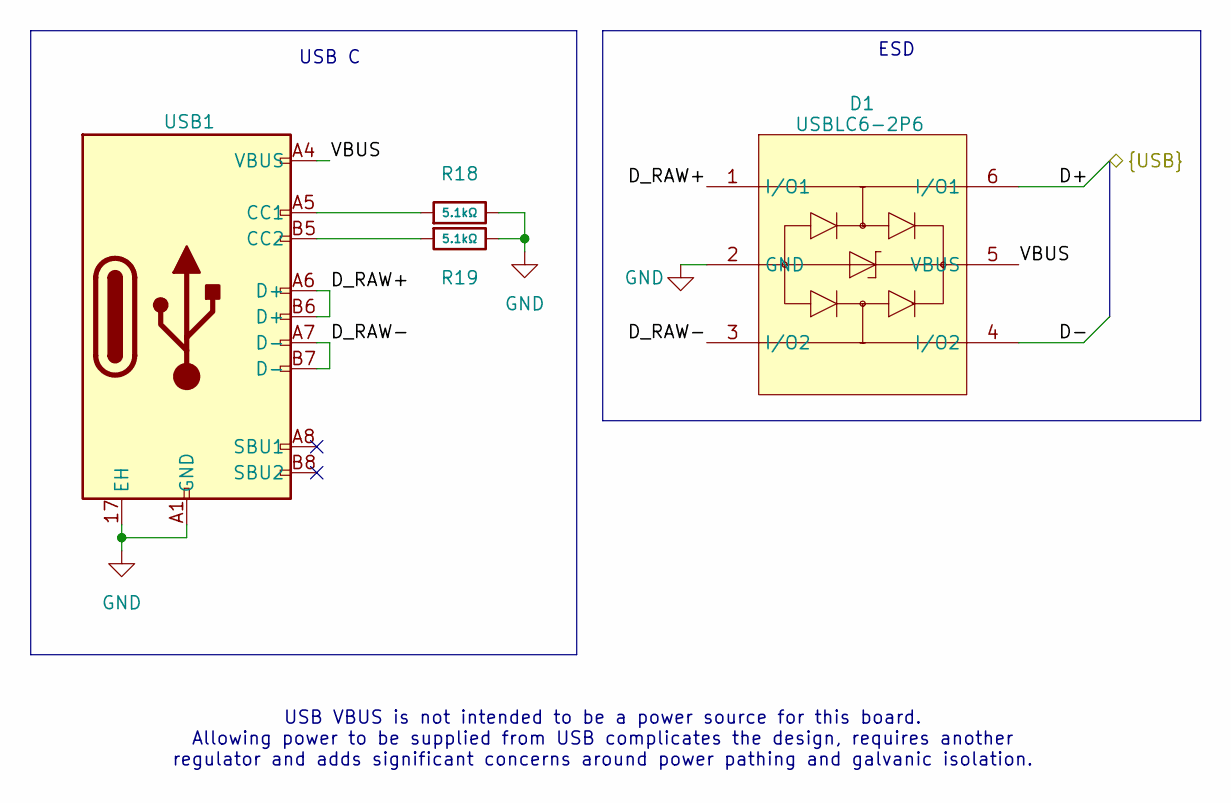
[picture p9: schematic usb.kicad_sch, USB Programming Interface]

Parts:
D1: USBLC6-2P6; SOT-666-6_L1.6-W1.2-P0.50-LS1.6-BR; MPN USBLC6-2P6; LCSC Part C15999
R18, R19: 5.1kΩ; R_0603; Overload Voltage (Max) 75V; Tolerance ±1%; Part 0603WAF5101T5E; LCSC C23186
USB1: GT-USB-7055BB; USB-C-TH_GT-USB-7055BB; MPN GT-USB-7055BB; LCSC Part C7450621

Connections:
/mcu/D+: D1.6 (I/O1); also elsewhere on the board
/mcu/D-: D1.4 (I/O2); also elsewhere on the board
/usb/D_RAW+: D1.1 (I/O1), USB1.A6 (D+), USB1.B6 (D+)
/usb/D_RAW-: D1.3 (I/O2), USB1.A7 (D-), USB1.B7 (D-)
/usb/VBUS: D1.5 (VBUS), USB1.A4 (VBUS), USB1.A9 (VBUS), USB1.B4 (VBUS), USB1.B9 (VBUS)
GND: D1.2 (GND), R18.2, R19.2, USB1.17 (EH), USB1.A1 (GND), USB1.A12 (GND), USB1.B1 (GND), USB1.B12 (GND); also elsewhere on the board
unnamed: R18.1, USB1.A5 (CC1)
unnamed: R19.1, USB1.B5 (CC2)

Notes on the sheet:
USB C
ESD
USB VBUS is not intended to be a power source for this board. Allowing power to be supplied from USB complicates the design, requires another regulator and adds significant concerns around power pathing and galvanic isolation.

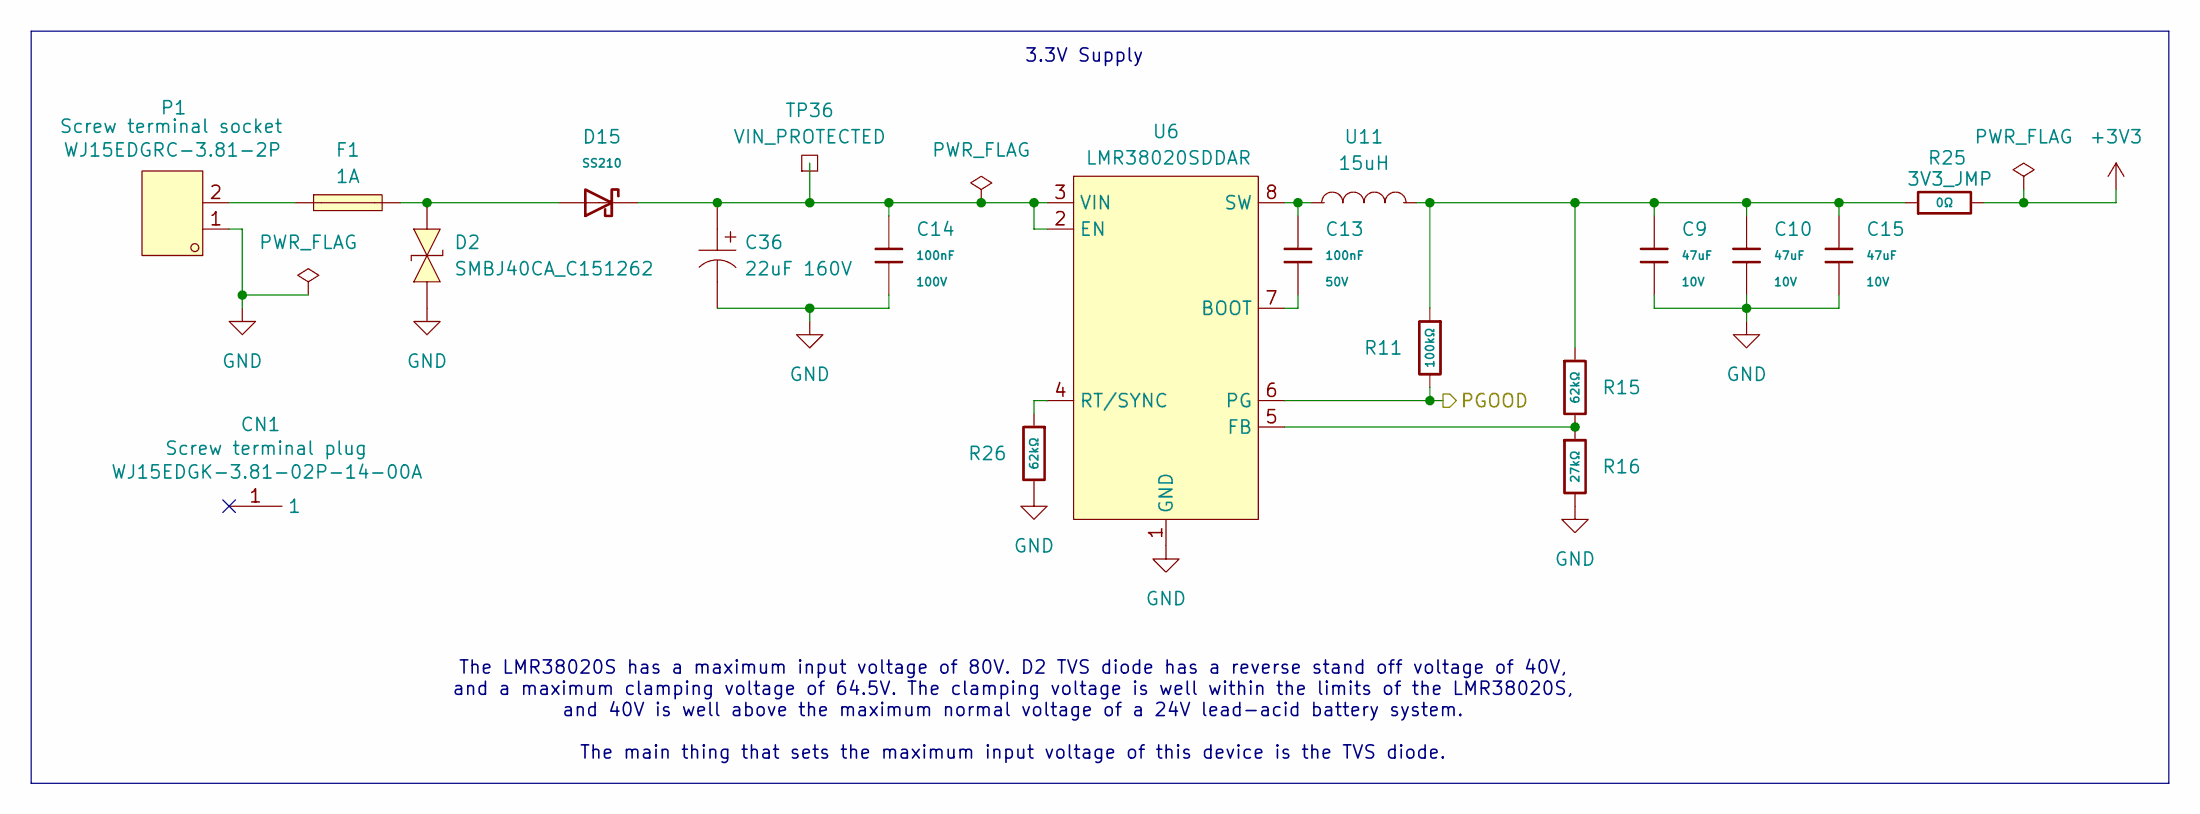
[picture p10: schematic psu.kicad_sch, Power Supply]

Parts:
C9, C10, C15: 47uF; C_1206; Voltage Rated 10V; Tolerance ±20%; Part CL31A476MPHNNNE; LCSC C96123
C13: 100nF; C_0603; Voltage Rated 50V; Tolerance ±10%; Part CC0603KRX7R9BB104; LCSC C14663
C14: 100nF; C_0805; Voltage Rated 100V; Tolerance ±10%; Part CL21B104KCFNNNE; LCSC C28233
C36: 22uF 160V; CAP-SMD_BD10.0-L10.3-W10.3-FD; MPN ULV2C220MNL1GS; LCSC Part C2164587
CN1: WJ15EDGK-3.81-02P-14-00A; FL_001; MPN WJ15EDGK-3.81-02P-14-00A; LCSC Part C8466
D2: SMBJ40CA_C151262; SMB_L4.6-W3.6-LS5.3-BI; MPN SMBJ40CA; LCSC Part C151262
D15: SS210; D_SMA; Forward Voltage (Vf@If) 850mV@2A; Reverse Voltage (Vr) 100V; Part SS210; LCSC C14996
F1: 1A; FUSE-SMD_L6.1-W2.6; MPN 0451001.MRL; LCSC Part C3099
P1: WJ15EDGRC-3.81-2P; CONN-TH_2P-P3.81_WJ15EDGRC-3.81-2P_CLIPPED; MPN WJ15EDGRC-3.81-02P-14-00A; LCSC Part C8387
R11: 100kΩ; R_0603; Overload Voltage (Max) 75V; Tolerance ±1%; Part 0603WAF1003T5E; LCSC C25803
R15, R26: 62kΩ; R_0603; Overload Voltage (Max) 75V; Tolerance ±1%; Part 0603WAF6202T5E; LCSC C23221
R16: 27kΩ; R_0603; Overload Voltage (Max) 75V; Tolerance ±1%; Part 0603WAF2702T5E; LCSC C22967
R25: 0Ω; R_0603; Overload Voltage (Max) 75V; Tolerance ±1%; Part 0603WAF0000T5E; LCSC C21189
TP36: VIN_PROTECTED; TestPoint_Plated_Hole_D2.0mm
U6: LMR38020SDDAR; ESOP-8_L4.9-W3.9-P1.27-LS6.0-BL-EP-1; MPN LMR38020SDDAR; LCSC Part C3192337
U11: 15uH; IND-SMD_L7.1-W6.6; MPN APH0630T150M; LCSC Part C5349699

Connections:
+3V3: R25.2; also elsewhere on the board
/mcu/PGOOD: R11.2, U6.6 (PG); also elsewhere on the board
GND: C9.2, C10.2, C14.2, C15.2, C36.2, D2.1 (K), P1.1, R16.2, R26.2, U6.1 (GND), U6.9 (GND); also elsewhere on the board
unnamed: C9.1, C10.1, C15.1, R11.1, R15.1, R25.1, U11.2
unnamed: D2.2 (A), D15.2, F1.2
unnamed: F1.1, P1.2
unnamed: C13.2, U6.7 (BOOT)
unnamed: C14.1, C36.1, D15.1, TP36.1 (1_1), U6.2 (EN), U6.3 (VIN)
unnamed: R15.2, R16.1, U6.5 (FB)
unnamed: R26.1, U6.4 (RT/SYNC)
unnamed: C13.1, U6.8 (SW), U11.1

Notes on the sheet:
The LMR38020S has a maximum input voltage of 80V. D2 TVS diode has a reverse stand off voltage of 40V, and a maximum clamping voltage of 64.5V. The clamping voltage is well within the limits of the LMR38020S, and 40V is well above the maximum normal voltage of a 24V lead-acid battery system. The ma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
3.3V Supply

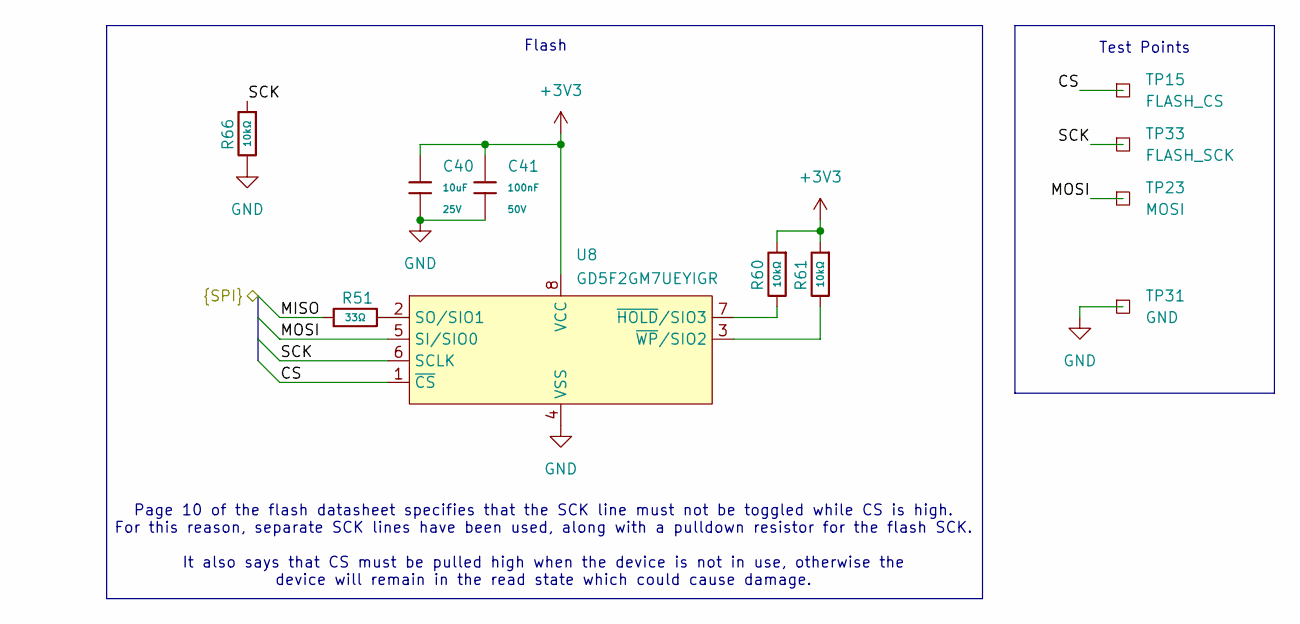
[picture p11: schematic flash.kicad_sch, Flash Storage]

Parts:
C40: 10uF; C_0603; Voltage Rated 25V; Tolerance ±20%; Part CL10A106MA8NRNC; LCSC C96446
C41: 100nF; C_0603; Voltage Rated 50V; Tolerance ±10%; Part CC0603KRX7R9BB104; LCSC C14663
R51: 33Ω; R_0603; Overload Voltage (Max) 75V; Tolerance ±1%; Part 0603WAF330JT5E; LCSC C23140
R60, R61, R66: 10kΩ; R_0603; Overload Voltage (Max) 75V; Tolerance ±1%; Part 0603WAF1002T5E; LCSC C25804
TP15: FLASH_CS; TestPoint_Pad_D1.0mm
TP23: MOSI; TestPoint_Pad_D1.0mm
TP31: GND; TestPoint_Plated_Hole_D2.0mm
TP33: FLASH_SCK; TestPoint_Pad_D1.0mm
U8: GD5F2GM7UEYIGR; WSON-8_L8.0-W6.0-P1.27-TL-1; MPN GD5F2GM7UEYIGR; LCSC Part C22412867

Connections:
+3V3: C40.2, C41.1, R60.1, R61.1, U8.8 (VCC); also elsewhere on the board
/flash/CS: TP15.1 (1_1), U8.1 (~CS); also elsewhere on the board
/flash/MISO: R51.1; also elsewhere on the board
/flash/MOSI: TP23.1 (1_1), U8.5 (SI/SIO0); also elsewhere on the board
/flash/SCK: R66.1, TP33.1 (1_1), U8.6 (SCLK); also elsewhere on the board
GND: C40.1, C41.2, R66.2, TP31.1 (1_1), U8.4 (VSS); also elsewhere on the board
unnamed: R51.2, U8.2 (SO/SIO1)
unnamed: R60.2, U8.7 (~HOLD/SIO3)
unnamed: R61.2, U8.3 (~WP/SIO2)

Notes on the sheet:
Page 10 of the flash datasheet specifies that the SCK line must not be toggled while CS is high. For this reason, separate SCK lines have been used, along with a pulldown resistor for the flash SCK. It also says that CS must be pulled high when the device is not in use, otherwise the device will re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
Test Points
Flash

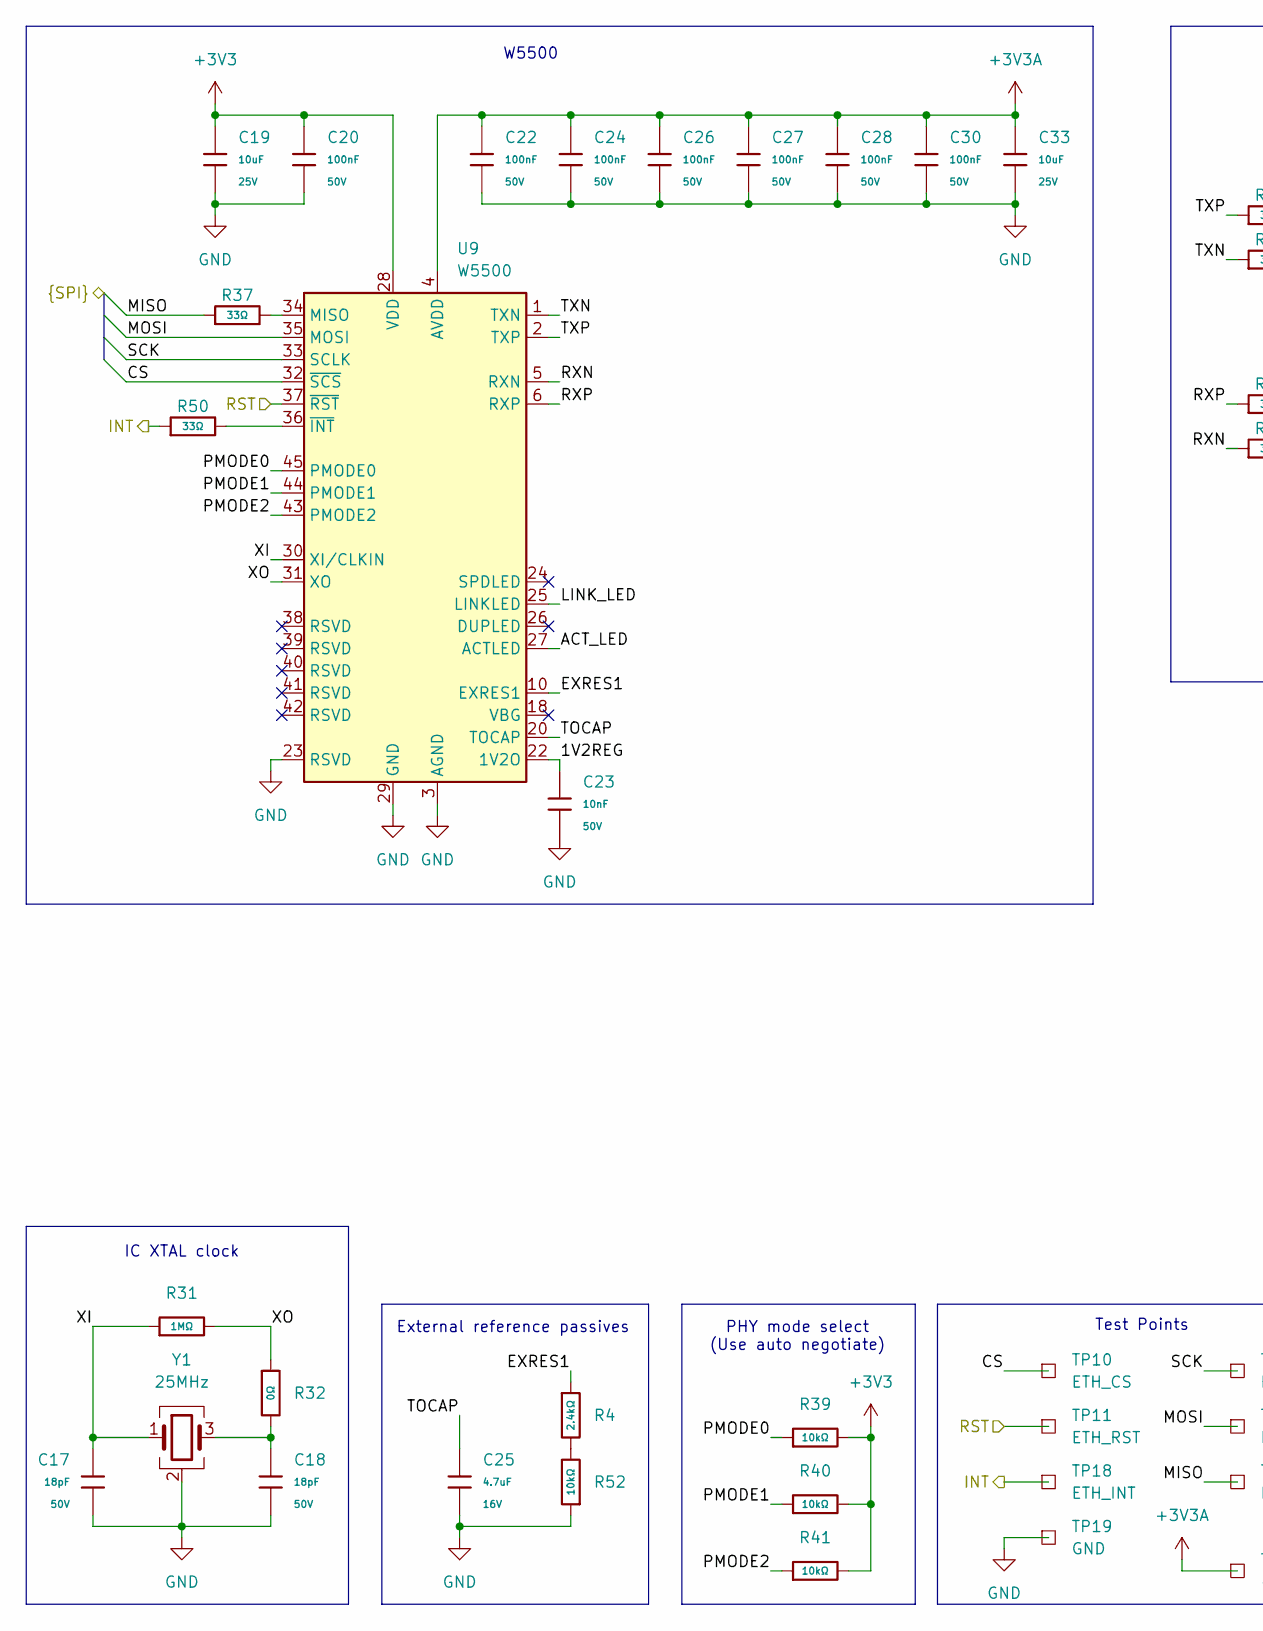
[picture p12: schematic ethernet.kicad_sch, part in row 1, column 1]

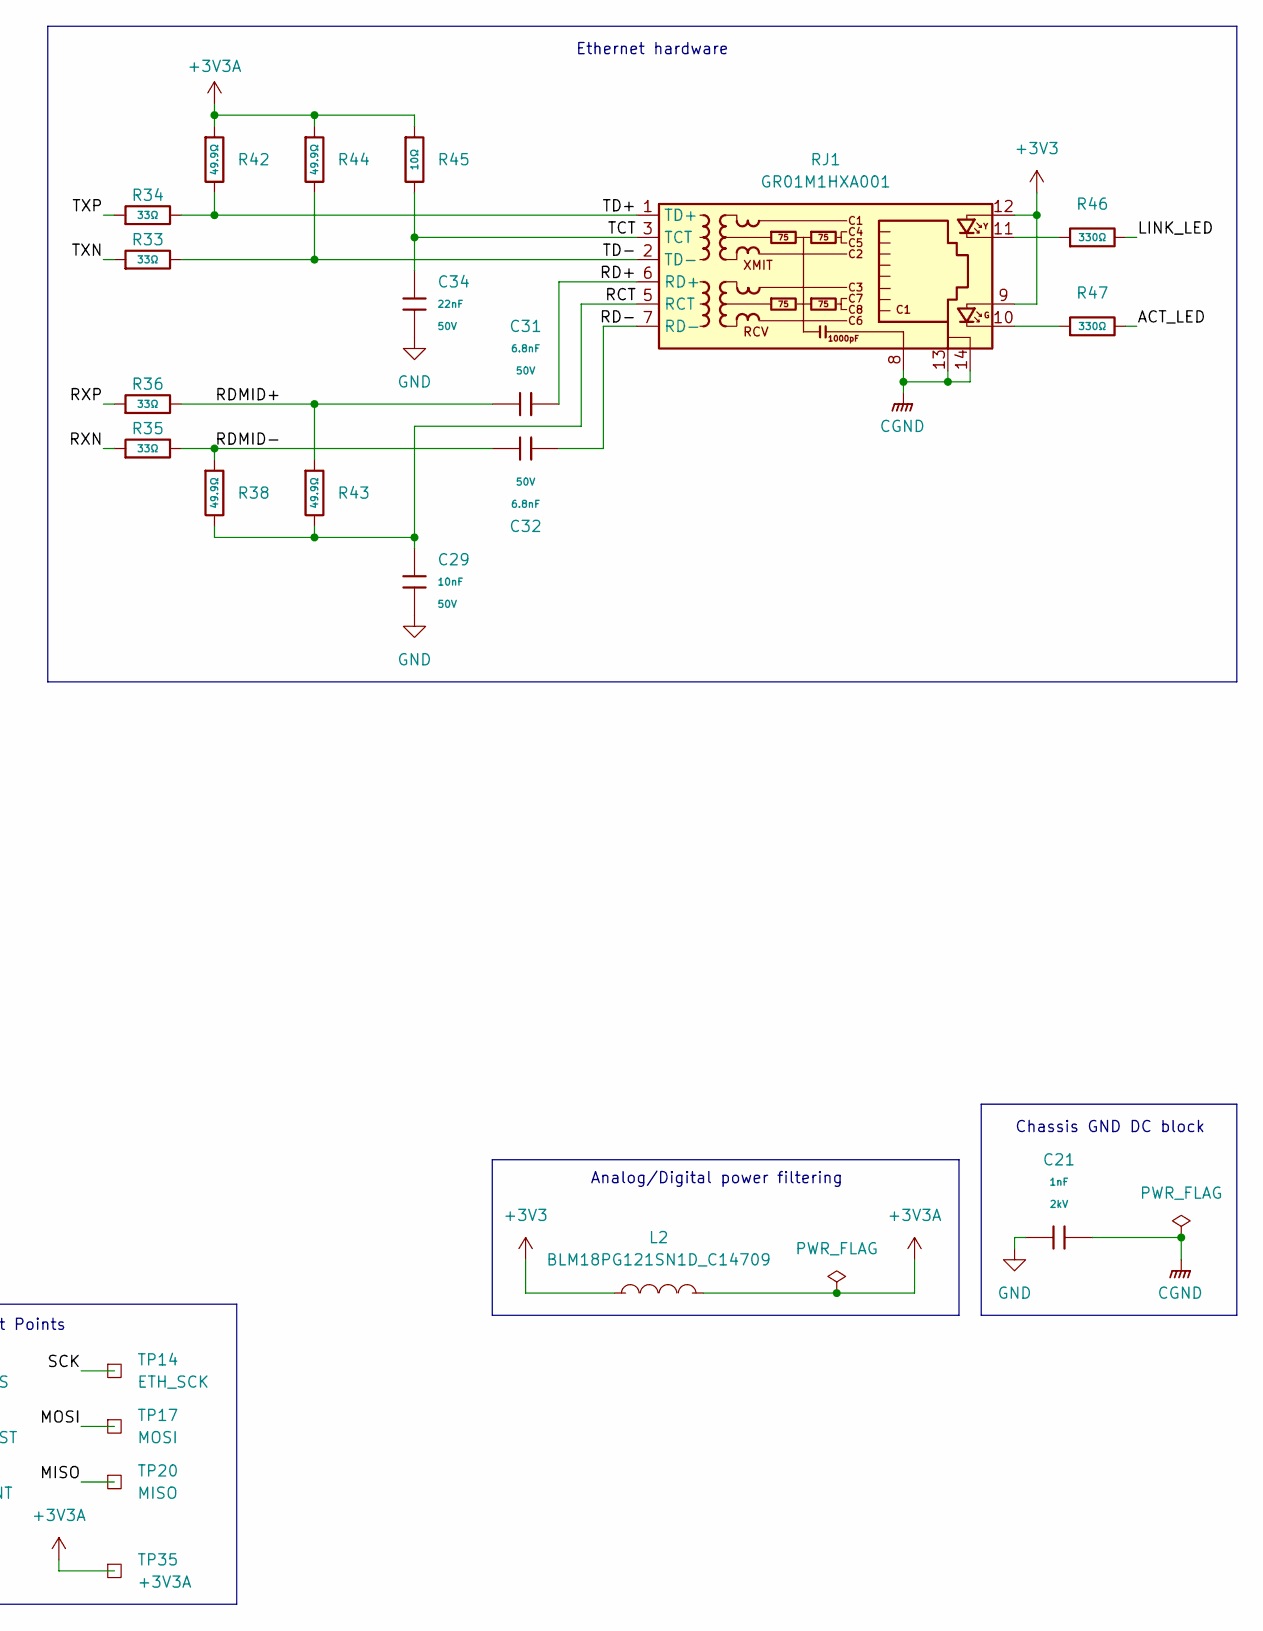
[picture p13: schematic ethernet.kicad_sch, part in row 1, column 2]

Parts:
C17, C18: 18pF; C_0603; Voltage Rated 50V; Tolerance ±5%; Part CL10C180JB8NNNC; LCSC C1647
C19, C33: 10uF; C_0603; Voltage Rated 25V; Tolerance ±20%; Part CL10A106MA8NRNC; LCSC C96446
C20, C22, C24, C26, C27, C28, C30: 100nF; C_0603; Voltage Rated 50V; Tolerance ±10%; Part CC0603KRX7R9BB104; LCSC C14663
C21: 1nF; C_1206; Voltage Rated 2kV; Tolerance ±10%; Part 1206B102K202NT; LCSC C9196
C23, C29: 10nF; C_0603; Voltage Rated 50V; Tolerance ±10%; Part 0603B103K500NT; LCSC C57112
C25: 4.7uF; C_0603; Voltage Rated 16V; Tolerance ±10%; Part CL10A475KO8NNNC; LCSC C19666
C31, C32: 6.8nF; C_0603; Voltage Rated 50V; Tolerance ±10%; Part 0603B682K500NT; LCSC C1631
C34: 22nF; C_0603; Voltage Rated 50V; Tolerance ±10%; Part CL10B223KB8NNNC; LCSC C21122
L2: BLM18PG121SN1D_C14709; L0603; MPN BLM18PG121SN1D; LCSC Part C14709
R4: 2.4kΩ; R_0603; Overload Voltage (Max) 75V; Tolerance ±1%; Part 0603WAF2401T5E; LCSC C22940
R31: 1MΩ; R_0603; Overload Voltage (Max) 75V; Tolerance ±1%; Part 0603WAF1004T5E; LCSC C22935
R32: 0Ω; R_0603; Overload Voltage (Max) 75V; Tolerance ±1%; Part 0603WAF0000T5E; LCSC C21189
R33, R34, R35, R36, R37, R50: 33Ω; R_0603; Overload Voltage (Max) 75V; Tolerance ±1%; Part 0603WAF330JT5E; LCSC C23140
R38, R42, R43, R44: 49.9Ω; R_0603; Overload Voltage (Max) 75V; Tolerance ±1%; Part 0603WAF499JT5E; LCSC C23185
R39, R40, R41, R52: 10kΩ; R_0603; Overload Voltage (Max) 75V; Tolerance ±1%; Part 0603WAF1002T5E; LCSC C25804
R45: 10Ω; R_0603; Overload Voltage (Max) 75V; Tolerance ±1%; Part 0603WAF100JT5E; LCSC C22859
R46, R47: 330Ω; R_0603; Overload Voltage (Max) 75V; Tolerance ±1%; Part 0603WAF3300T5E; LCSC C23138
RJ1: GR01M1HXA001; RJ45-TH_GR01M1HXA001; MPN GR01M1HXA001; LCSC Part C4155019
TP10: ETH_CS; TestPoint_Pad_D1.0mm
TP11: ETH_RST; TestPoint_Pad_D1.0mm
TP14: ETH_SCK; TestPoint_Pad_D1.0mm
TP17: MOSI; TestPoint_Pad_D1.0mm
TP18: ETH_INT; TestPoint_Pad_D1.0mm
TP19: GND; TestPoint_Plated_Hole_D2.0mm
TP20: MISO; TestPoint_Pad_D1.0mm
TP35: +3V3A; TestPoint_Pad_D1.0mm
U9: W5500; LQFP-48_7x7mm_P0.5mm; MPN W5500; LCSC Part C32843
Y1: 25MHz; OSC-SMD_4P-L3.2-W2.5-BL; MPN X322525MOB4SI; LCSC Part C9006

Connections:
+3V3: C19.1, C20.1, L2.1, R39.2, R40.2, R41.2, RJ1.9, RJ1.12, U9.28 (VDD); also elsewhere on the board
+3V3A: C22.1, C24.1, C26.1, C27.1, C28.1, C30.1, C33.1, L2.2, R42.1, R44.1, R45.1, TP35.1 (1_1), U9.4 (AVDD), U9.8 (AVDD), U9.11 (AVDD), U9.15 (AVDD), U9.17 (AVDD), U9.21 (AVDD)
/ethernet/1V2REG: C23.1, U9.22 (1V2O)
/ethernet/ACT_LED: R47.2, U9.27 (ACTLED)
/ethernet/CS: TP10.1 (1_1), U9.32 (~SCS); also elsewhere on the board
/ethernet/EXRES1: R4.1, U9.10 (EXRES1)
/ethernet/INT: R50.1, TP18.1 (1_1); also elsewhere on the board
/ethernet/LINK_LED: R46.2, U9.25 (LINKLED)
/ethernet/MISO: R37.1, TP20.1 (1_1); also elsewhere on the board
/ethernet/MOSI: TP17.1 (1_1), U9.35 (MOSI); also elsewhere on the board
/ethernet/PMODE0: R39.1, U9.45 (PMODE0)
/ethernet/PMODE1: R40.1, U9.44 (PMODE1)
/ethernet/PMODE2: R41.1, U9.43 (PMODE2)
/ethernet/RCT: C29.1, R38.2, R43.2, RJ1.5 (RCT)
/ethernet/RD+: C31.2, RJ1.6 (RD+)
/ethernet/RD-: C32.2, RJ1.7 (RD-)
/ethernet/RDMID+: C31.1, R36.2, R43.1
/ethernet/RDMID-: C32.1, R35.2, R38.1
/ethernet/RXN: R35.1, U9.5 (RXN)
/ethernet/RXP: R36.1, U9.6 (RXP)
/ethernet/SCK: TP14.1 (1_1), U9.33 (SCLK); also elsewhere on the board
/ethernet/TCT: C34.1, R45.2, RJ1.3 (TCT)
/ethernet/TD+: R34.2, R42.2, RJ1.1 (TD+)
/ethernet/TD-: R33.2, R44.2, RJ1.2 (TD-)
/ethernet/TOCAP: C25.1, U9.20 (TOCAP)
/ethernet/TXN: R33.1, U9.1 (TXN)
/ethernet/TXP: R34.1, U9.2 (TXP)
/ethernet/XI: C17.1, R31.1, U9.30 (XI/CLKIN), Y1.1
/ethernet/XO: R31.2, R32.1, U9.31 (XO)
/mcu/ETH_RST: TP11.1 (1_1), U9.37 (~RST); also elsewhere on the board
CGND: C21.2, RJ1.8, RJ1.13, RJ1.14
GND: C17.2, C18.2, C19.2, C20.2, C21.1, C22.2, C23.2, C24.2, C25.2, C26.2, C27.2, C28.2, C29.2, C30.2, C33.2, C34.2, R52.1, TP19.1 (1_1), U9.3 (AGND), U9.9 (AGND), U9.14 (AGND), U9.16 (AGND), U9.19 (AGND), U9.23 (RSVD), U9.29 (GND), U9.48 (AGND), Y1.2 (G), Y1.4 (G); also elsewhere on the board
unnamed: C18.1, R32.2, Y1.3
unnamed: R4.2, R52.2
unnamed: R46.1, RJ1.11
unnamed: R47.1, RJ1.10
unnamed: R37.2, U9.34 (MISO)
unnamed: R50.2, U9.36 (~INT)

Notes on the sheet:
Chassis GND DC block
IC XTAL clock
W5500
Ethernet hardware
Analog/Digital power filtering
Test Points
External reference passives
PHY mode select (Use auto negotiate)

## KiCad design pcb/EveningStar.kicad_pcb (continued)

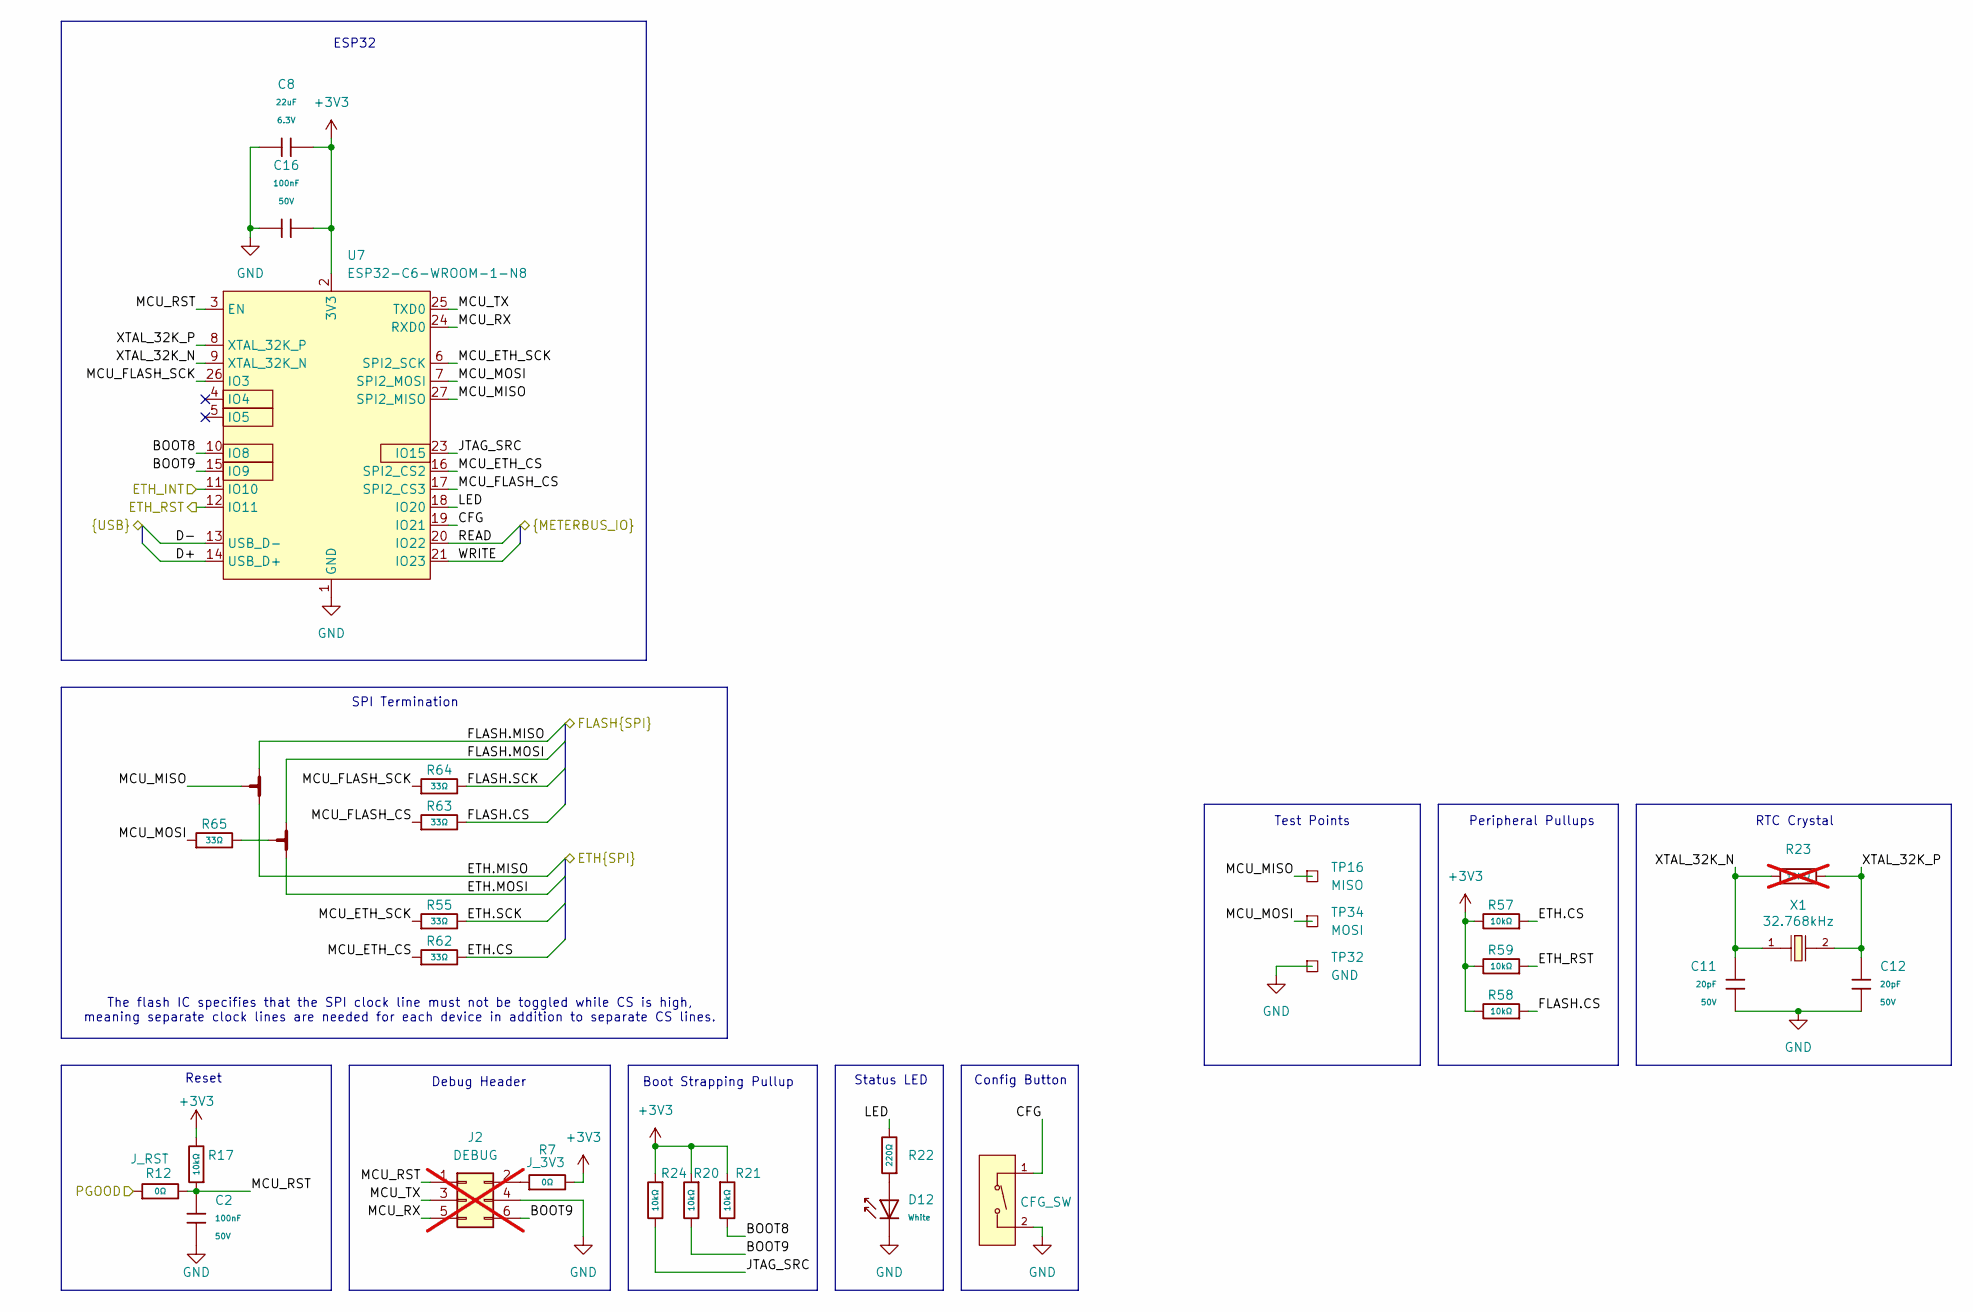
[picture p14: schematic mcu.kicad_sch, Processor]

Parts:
C2, C16: 100nF; C_0603; Voltage Rated 50V; Tolerance ±10%; Part CC0603KRX7R9BB104; LCSC C14663
C8: 22uF; C_0603; Voltage Rated 6.3V; Tolerance ±20%; Part CL10A226MQ8NRNC; LCSC C59461
C11, C12: 20pF; C_0603; Voltage Rated 50V; Tolerance ±5%; Part CL10C200JB8NNNC; LCSC C1648
D12: White; D_0805; Part KT-0805W; LCSC C34499
J2: DEBUG; PinHeader_2x03_P2.54mm_Vertical; not fitted
NT2: NetTie_3_Tee; NetTie-3_SMD_Pad0.5mm_Stock
NT3: NetTie_3_Tee; NetTie-3_SMD_Pad0.5mm
R7, R12: 0Ω; R_0603; Overload Voltage (Max) 75V; Tolerance ±1%; Part 0603WAF0000T5E; LCSC C21189
R17, R20, R21, R24, R57, R58, R59: 10kΩ; R_0603; Overload Voltage (Max) 75V; Tolerance ±1%; Part 0603WAF1002T5E; LCSC C25804
R22: 220Ω; R_0603; Overload Voltage (Max) 75V; Tolerance ±1%; Part 0603WAF2200T5E; LCSC C22962
R23: 10MΩ; R_0603; Overload Voltage (Max) 75V; Tolerance ±1%; Part 0603WAF1005T5E; LCSC C7250; not fitted
R55, R62, R63, R64, R65: 33Ω; R_0603; Overload Voltage (Max) 75V; Tolerance ±1%; Part 0603WAF330JT5E; LCSC C23140
S1: Tactile Button, 160gf; SW_TS-1088-AR02016; Voltage Rating (Dc) 12V; Part TS-1088-AR02016; LCSC C720477
TP16: MISO; TestPoint_Pad_D1.0mm
TP32: GND; TestPoint_Plated_Hole_D2.0mm
TP34: MOSI; TestPoint_Pad_D1.0mm
U7: ESP32-C6-WROOM-1-N8; WIRELM-SMD_ESP32-C6-WROOM-1; MPN ESP32-C6-WROOM-1-N8; LCSC Part C5366877
X1: 32.768kHz; FC-135R_L3.2-W1.5; Frequency Tolerance ±20ppm; Part Q13FC13500004; LCSC C32346

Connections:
+3V3: C8.2, C16.1, R7.2, R17.2, R20.1, R21.1, R24.1, R57.2, R58.2, R59.2, U7.2 (3V3); also elsewhere on the board
/ethernet/CS: R57.1, R62.2; also elsewhere on the board
/ethernet/INT: U7.11 (IO10); also elsewhere on the board
/ethernet/MISO: NT3.2; also elsewhere on the board
/ethernet/MOSI: NT2.2; also elsewhere on the board
/ethernet/SCK: R55.2; also elsewhere on the board
/flash/CS: R58.1, R63.2; also elsewhere on the board
/flash/MISO: NT3.1; also elsewhere on the board
/flash/MOSI: NT2.1; also elsewhere on the board
/flash/SCK: R64.2; also elsewhere on the board
/mcu/BOOT8: R21.2, U7.10 (IO8)
/mcu/BOOT9: J2.6, R20.2, U7.15 (IO9)
/mcu/CFG: S1.1 (A), U7.19 (IO21)
/mcu/D+: U7.14 (USB_D+); also elsewhere on the board
/mcu/D-: U7.13 (USB_D-); also elsewhere on the board
/mcu/ETH_RST: R59.1, U7.12 (IO11); also elsewhere on the board
/mcu/JTAG_SRC: R24.2, U7.23 (IO15)
/mcu/LED: R22.2, U7.18 (IO20)
/mcu/MCU_ETH_CS: R62.1, U7.16 (SPI2_CS2)
/mcu/MCU_ETH_SCK: R55.1, U7.6 (SPI2_SCK)
/mcu/MCU_FLASH_CS: R63.1, U7.17 (SPI2_CS3)
/mcu/MCU_FLASH_SCK: R64.1, U7.26 (IO3)
/mcu/MCU_MISO: NT3.3, TP16.1 (1_1), U7.27 (SPI2_MISO)
/mcu/MCU_MOSI: R65.1, TP34.1 (1_1), U7.7 (SPI2_MOSI)
/mcu/MCU_RST: C2.1, J2.1, R12.2, R17.1, U7.3 (EN)
/mcu/MCU_RX: J2.5, U7.24 (RXD0)
/mcu/MCU_TX: J2.3, U7.25 (TXD0)
/mcu/PGOOD: R12.1; also elsewhere on the board
/mcu/READ: U7.20 (IO22); also elsewhere on the board
/mcu/WRITE: U7.21 (IO23); also elsewhere on the board
/mcu/XTAL_32K_N: C11.1, R23.1, U7.9 (XTAL_32K_N), X1.1
/mcu/XTAL_32K_P: C12.1, R23.2, U7.8 (XTAL_32K_P), X1.2
GND: C2.2, C8.1, C11.2, C12.2, C16.2, D12.1, J2.4, S1.2 (B), TP32.1 (1_1), U7.1 (GND), U7.28 (GND), U7.29 (GND); also elsewhere on the board
unnamed: D12.2, R22.1
unnamed: J2.2, R7.1
unnamed: NT2.3, R65.2

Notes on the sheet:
Debug Header
RTC Crystal
Reset
ESP32
SPI Termination
Peripheral Pullups
The flash IC specifies that the SPI clock line must not be toggled while CS is high, meaning separate clock lines are needed for each device in addition to separate CS lines.
Status LED
Config Button
Test Points
Boot Strapping Pullup

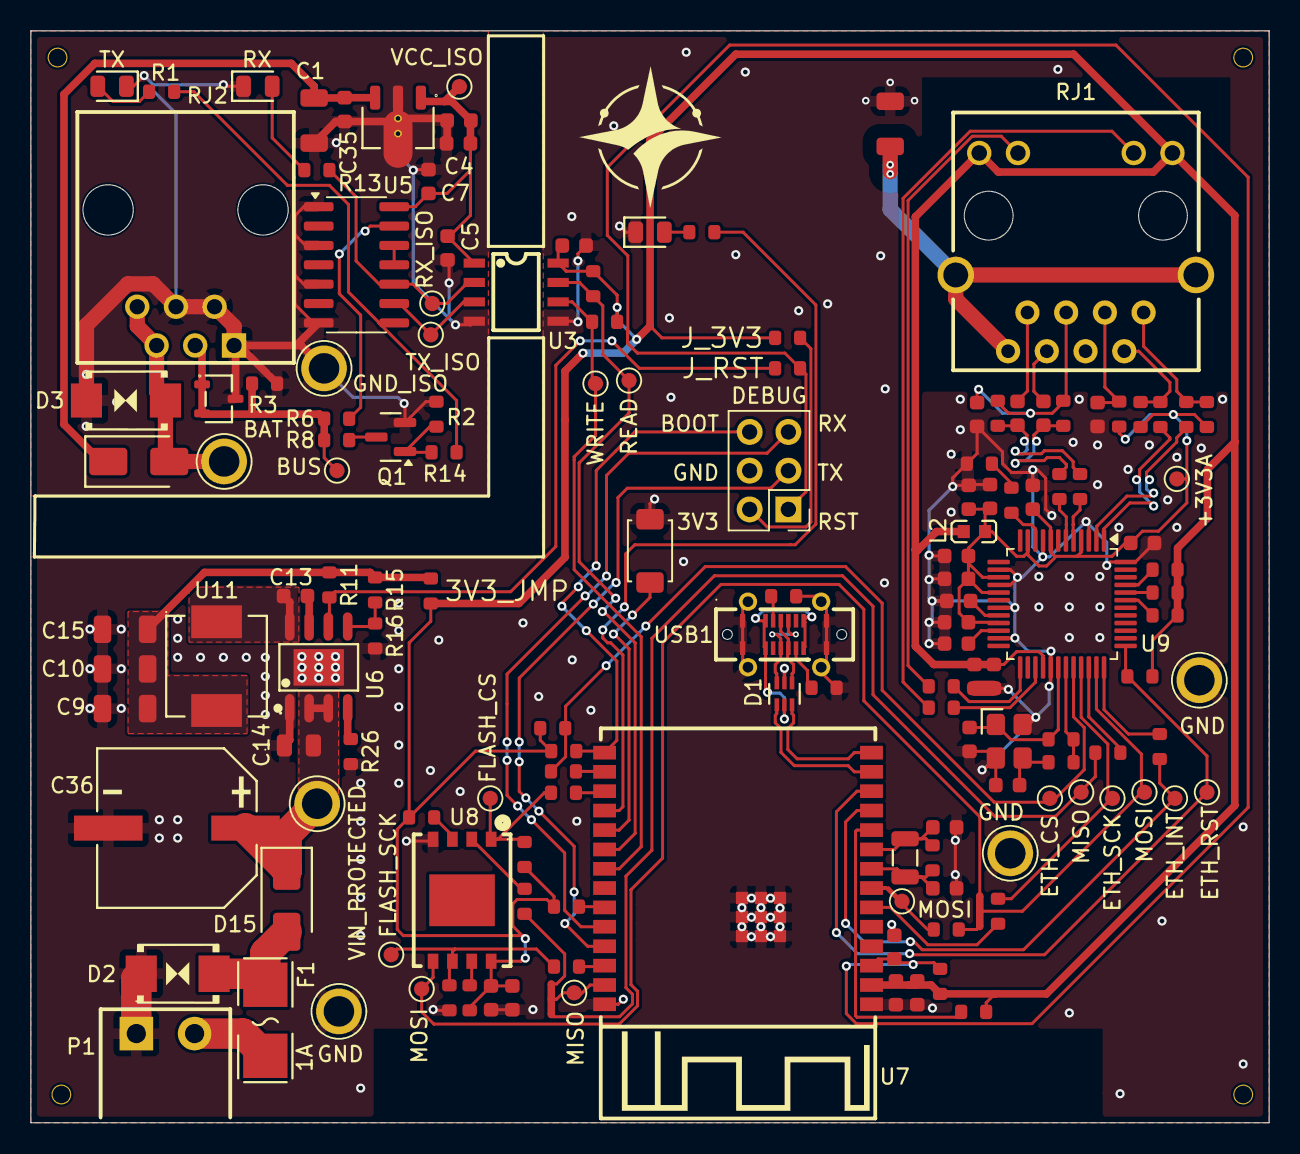
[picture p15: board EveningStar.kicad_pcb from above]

Board: 2 copper layers, 81.2 x 71.6 mm, 152 parts (0 on the bottom side), 96 nets.

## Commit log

2026-05-12 feat: add partial design of bus interface schematic
    [EveningStar.kicad_pcb, EveningStar.kicad_sch]
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2026-05-13 feat: implement more of the meterbus side isolated circuit
    [EveningStar.kicad_sch]
2026-05-14 feat: add 3.3V PSU
    [EveningStar.kicad_sch, meterbus_frontend.kicad_sch, psu.kicad_sch]
2026-05-14 feat: add MCU sheet with USB, reset and programming circuitry
    [EveningStar.kicad_sch, mcu.kicad_sch, psu.kicad_sch]
2026-05-14 feat: add W5500 ethernet controller
    [EveningStar.kicad_pcb, EveningStar.kicad_sch, ethernet.kicad_sch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]
2026-05-14 feat: connect ethernet to mcu and sort erc errors
    [EveningStar.kicad_sch, ethernet.kicad_sch, mcu.kicad_sch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]
2026-05-15 feat: update compoents with lcsc parts
    [EveningStar.kicad_pcb, ethernet.kicad_sch, mcu.kicad_sch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]
2026-05-16 feat: layout meterbus frontend
    [EveningStar.kicad_pcb, ethernet.kicad_sch, mcu.kicad_sch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]
2026-05-16 fix: flip rj11 meterbus connector
    [EveningStar.kicad_pcb, meterbus_frontend.kicad_sch]
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2026-05-16 feat: roughly lay out mcu
    [EveningStar.kicad_pcb, ethernet.kicad_sch, mcu.kicad_sch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]
2026-05-16 feat: add filled zones
    [EveningStar.kicad_pcb]
2026-05-17 feat: layout psu and rest of mcu
    [EveningStar.kicad_pcb, mcu.kicad_sch, psu.kicad_sch]
2026-05-17 fix: appease drc
    [EveningStar.kicad_pcb]
2026-05-17 feat: create pcb production files and swap some parts for basic
    [EveningStar.kicad_pcb, EveningStar.kicad_sch, bom.csv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]
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2026-05-17 fix: swap meterbus tx mosfet for jlc basic part
    [EveningStar.kicad_pcb, bom.csv, designators.csv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]
2026-05-18 feat: replace many parts for basic parts
    [EveningStar.kicad_pcb, bom.csv, designators.csv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]
2026-05-18 fix: rotate parts for correct soldering
    [positions.csv]
2026-05-18 nfc: typo and no board change
    [EveningStar.kicad_pcb]
2026-05-19 fix: add easyeda library to source control
    [mcu.kicad_sch]
2026-05-19 fix: add direction marker on silkscreen for AHT20
    [EveningStar.kicad_pcb]
2026-05-19 fix: add missing top copper pour on meterbus side
    [EveningStar.kicad_pcb]
2026-05-19 fix: update isolation keep out zone
    [EveningStar.kicad_pcb]
2026-05-19 fix: add fill keep out zone for temp sensor
    [EveningStar.kicad_pcb]
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2026-06-28 Squashed 'pcb/lib/JLCPCB-Kicad-Library/' content from commit bb27d66
    git-subtree-dir: pcb/lib/JLCPCB-Kicad-Library
    git-subtree-split: bb27d660dea73056d1024c0ccda3216ddcb60590
    [AUDIO-TH_PJ-3850-5A.step, BAT-TH_BS-07-A1BJ001.step, CAP-SMD_BD8.0-L8.3-W8.3-FD.step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]
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2026-06-28 pcb: update symbols and footprints to fix drc
    [EveningStar.kicad_pcb, ethernet.kicad_sch, mcu.kicad_sch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]
2026-06-28 pcb: fix symbol paths for github actions check
2026-06-28 pcb: update drifted oscillator footprint
    [ethernet.kicad_sch]
2026-06-28 pcb: add check for jlcpcb subtree lib drift
2026-06-28 pcb: switch 3d model path
    [EveningStar.kicad_pcb]
2026-06-28 pcb: fix 3d offsets for parts
    [EveningStar.kicad_pcb]
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2026-06-28 pcb: fix easyeda 3d model path
    [EveningStar.kicad_pcb]
2026-06-28 pcb: refactor custom libraries into folder
    [EveningStar.kicad_pcb]
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2026-07-19 tooling: make production artifacts reproducible
    [bom.csv, designators.csv, jlcpcb-placement-overrides.csv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]
2026-07-19 hardware: correct 3.3 V regulator ordering data
    [EveningStar.kicad_pcb, psu.kicad_sch]
2026-07-19 tooling: address production review feedback
    [EveningStar.kicad_pcb, jlcpcb-placement-overrides.csv]
2026-07-20 pcb: refresh saved zone fills
    [EveningStar.kicad_pcb]
2026-07-20 pcb: flatten project library layout
    [EveningStar.kicad_pcb]
2026-08-01 sch: remove 3.3v jumper
    Fixes #16
    [EveningStar.kicad_pcb, psu.kicad_sch]
2026-08-01 sch: clean up ethernet schematic
    [EveningStar.kicad_sch, ethernet.kicad_sch]
2026-08-01 sch: remove usb power and clean up mcu sheet
    Fixes #15
    [EveningStar.kicad_sch, ethernet.kicad_sch, mcu.kicad_sch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]
2026-08-01 sch: move usb to separate sheet
    [EveningStar.kicad_sch, mcu.kicad_sch, temp_humidity.kicad_sch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]
2026-08-01 sch: replace mcu and clean up schematic
    Fixes #27
    [EveningStar.kicad_sch, ethernet.kicad_sch, mcu.kicad_sch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]
2026-08-01 sch: add flash ic
    Fixes #11
    [EveningStar.kicad_sch, flash.kicad_sch, mcu.kicad_sch]
2026-08-01 sch: add 32khz rtc crystal
    Fixes #21
    [EveningStar.kicad_sch, flash.kicad_sch, mcu.kicad_sch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]
2026-08-01 sch: fix some drc errors
    [flash.kicad_sch, mcu.kicad_sch, rtc.kicad_sch]
2026-08-01 sch: replace green led resistor
    Fixes #6
    [meterbus_frontend.kicad_sch]
2026-08-01 sch: replace meterbus led resistors again
    Fixes #46
    [meterbus_frontend.kicad_sch]
2026-08-01 sch: remove ineffective meterbus pullup resistor
    [meterbus_frontend.kicad_sch]
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2026-08-01 sch: remove aht20 temp humidity sensor
    Fixes #49
    [EveningStar.kicad_sch, mcu.kicad_sch, temp_humidity.kicad_sch]
2026-08-01 sch: switch to vertical usb c and replace esd ic
    This replaces the existing edge-mount USB C connector for a vertical one to ease routing and placement. Also swaps the unsuitable ESD IC with a specific USB ESD protection IC. Relates to #1
    [usb.kicad_sch]
2026-08-01 sch: switch to vertical ethernet jack
    Replace the original right-angled ethernet connector with a vertical one to make routing and placement easier. Relates to #42
    [ethernet.kicad_sch]
2026-08-01 sch: switch to vertical meterbus jack
    Replace the original right-angled RJ11 meterbus connector with a vertical one to make routing and placement easier. Relates to #42
    [meterbus_frontend.kicad_sch]
2026-08-01 sch: remove reset switch
    It's reasonable to power cycle the device to reset it, or use the programming header/USB C when flashing. This improves moisture resilience, reduces cost and simplifies the design.
    [mcu.kicad_sch]
2026-08-01 sch: revert debug/flash header to espprog format
    Had previously added IO8 to this header, but have confirmed it's not needed for flashing via UART. The header is now ESPPROG compatible, and I've confirmed flashing works with an ESPPROG flasher device on the V1 board revision which uses the same pinout. Fixes #50
    [mcu.kicad_sch]
2026-08-01 sch: highlight esp strapping pins and avoid using them
    Moves the ETH_INT and ETH_RST pins to avoid the strapping pins on the
    ESP, and also adds a pullup on IO15 to avoid edge case where JTAG source
    efuse is set and the pin is left floating which could disrupt USB JTAG.
    Fixes #26
    [mcu.kicad_sch]
2026-08-01 sch: replace hanrun ethernet jack with one rated for lower temperature
    This board will likely end up in places that are quite cold, so there is a need to use a lower temperature rated ethernet jack since the HanRun one was only rated down to 0C
    [ethernet.kicad_sch]
2026-08-01 sch: replace power supply IC with LMR38020S and use screw terminals
    This DC-DC IC is a better fit for the maximum voltages of a 24VDC
    lead-acid battery system, and allows plenty of headroom for appropriate
    TVS diode selection. Fixes #53
    Also replaces the DC barrel jack with pluggable screw terminals. Fixes
    #30
    [psu.kicad_sch]
2026-08-01 sch: add 1A fuse
    Adds a 1A fuse before the TVS diodes. Helps protect against shorted input caps or large overvoltage surge. Fixes #44
    [psu.kicad_sch]
2026-08-01 sch: reset esp32 using dc-dc pgood line
    This avoids the needs for a voltage supervisor, and provides some protection against brownouts and glitches
    [EveningStar.kicad_sch, mcu.kicad_sch]
2026-08-01 sch: fix a bunch of psu drc errors
    There were missing power flags, unspecified pin types and a missing connection between SW and feedback divider on the DC-DC IC
    [psu.kicad_sch]
2026-08-02 sch: adjust test points
    Removes some test points, and adds useful ones to data lines. Fixes #19
    [ethernet.kicad_sch, flash.kicad_sch, mcu.kicad_sch]
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2026-08-02 docs: rewrite the README for the V1 board
    Replace the feature list, debug LED section, and hardware observations with a
    short description of what the board is and does.
    Correct the parts that no longer describe V1. The bus input has no PTC; the
    only fuse is a 1 A cartridge on the DC input, alongside a TVS and a reverse
    polarity diode. Isolation, the half-duplex open-drain bus interface, and the
    Schmitt-trigger receive path are real and kept, and Ethernet, USB-C, and the
    SPI NAND are described where the old text did not mention them.
2026-08-15 sch: replace meterbus psu
    Replaces the AMS1117-5 regulator with a HT7533 3.3v regulator which has
    a much wider input range, allowing for more appropriate TVS diode
    protection.
    Also rejigs some test points.
    Relates to #48
    [meterbus_frontend.kicad_sch]
2026-08-15 sch: update meterbus frontend
    Fixes #48
    This is a complete rework of the Meterbus frontend, including power
    supply IC replacement, gate IC replacement, ESD protection adjustments,
    LED resistor adjustments, and general schematic cleanup.
    The other major change is the removal of the bus input voltage divider,
    which has been replaced with a series limiter and a clamping design
    using the internal clamp diodes of the HC14 (Explicitly supported by
    Nexperia)
    [meterbus_frontend.kicad_sch]
2026-08-15 sch: add schematic titles and do some cleanup
    [EveningStar.kicad_sch, ethernet.kicad_sch, flash.kicad_sch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]
2026-08-15 sch: fix erc errors
    Fixes some simple ERC errors related to unspecified pin types for
    components.
    [meterbus_frontend.kicad_sch]
2026-08-15 sch: add schematic descriptions
    [ethernet.kicad_sch, flash.kicad_sch, mcu.kicad_sch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]
2026-08-15 sch: fix test point label
    [meterbus_frontend.kicad_sch]
2026-08-15 sch: add note about usb power
    [usb.kicad_sch]
2026-08-15 sch: rewire SPI to supply separate clock lines to flash and ethernet
    The flash IC datasheet specifies that the SPI clock must not be toggled
    while CS is high, which means we need to separate the ethernet and flash
    clock lines.
    I've GPIO3 on the ESP for the flash clock line, and plan to use the
    internal peripheral MUX to switch it when talking with the IC.
    I've also moved a bunch of test points and termination resistors in this
    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
    [EveningStar.kicad_sch, ethernet.kicad_sch, flash.kicad_sch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]
2026-08-15 sch: connect reserved W5500 pin 23 to ground
    Pin 23 should be tied to ground according to the datasheet.
    [ethernet.kicad_sch]
2026-08-15 sch: replace 12.2k w5500 exres with 12.4k
    Datasheet specifies 12.4k resistor not 12.2k which was a mistake
    [ethernet.kicad_sch]
2026-08-15 sch: add 3V3A ethernet TP
    [ethernet.kicad_sch]
2026-08-15 sch: increase bulk bypass capacitance for ESP32
    WiFi tx and other intensive operations can chug a bit of current, so
    increase to 22uF
    [mcu.kicad_sch]
2026-08-15 sch: replace bus drive mosfet with 2N7002
    The 2N7002 has higher voltage rating and costs less than the AO3400A.
    It still has an appropriate 7 ohm RDSon @ 5V
    [meterbus_frontend.kicad_sch]
2026-08-15 sch: add missing psu output capacitance
    Forgot to add output capcitance to the 3.3V PSU
    [psu.kicad_sch]
2026-08-15 sch: add more input capacitance for 3.3v psu
    Input capacitance was quite low, especially considering MLCC derating
    [psu.kicad_sch]
2026-08-15 sch: add test point for protected battery vin rail
    [psu.kicad_sch]
2026-08-15 sch: rename meterbus power rail label
    The old label BATT_ISO was a bit confusing, and I think MB_PWR_ISO is
    more accurate
    [meterbus_frontend.kicad_sch]
2026-08-15 sch: add note about meterbus power supply max voltage
    [meterbus_frontend.kicad_sch]
2026-08-16 lib: move customized JLCPCB symbols into custom library
    Three JLCPCB symbols had pin electrical types edited in place in the
    vendored subtree, which the subtree drift check rejects. Copy them into
    custom_symbols under their MPNs, repoint the schematic, and restore the
    subtree to its recorded squash commit.
    X1 Crystal, 32.768kHz, 13pF -> custom_symbols:Q13FC1350000400
    D7 TVS-Bi, PSM712-LF-T7 -> custom_symbols:PSM712-LF-T7
    U1 LDO, 5V, 0.1A -> custom_symbols:78L05G
    Pin geometry is unchanged, so existing wiring is unaffected. The fourth
    edited symbol, LDO, 3.3V, 0.1A (HT7533), is no longer used by the board
    and was dropped rather than copied.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
    [mcu.kicad_sch, meterbus_frontend.kicad_sch]
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2026-08-16 sch: add frequency value to rtc crystal
    [mcu.kicad_sch]
2026-08-22 pcb: layout and route meterbus frontend
    Places parts PCB traces for MeterBus frontend.
    Also changes which gates on HC14 schematic are used to simplify routing.
    [EveningStar.kicad_pcb, meterbus_frontend.kicad_sch]
2026-08-22 pcb: fix 3d models
    [EveningStar.kicad_pcb]
2026-08-22 pcb: compact meterbus frontend layout
    [EveningStar.kicad_pcb]
2026-08-22 pcb: adjust drc rules to match jlc
    [EveningStar.kicad_pcb, meterbus_frontend.kicad_sch]
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2026-08-22 pcb(mb_frontend): clean up silkscreen labels
    [EveningStar.kicad_pcb]
2026-08-22 pcb(mb_frontend): fix drc silk clearance warnings
    [EveningStar.kicad_pcb, meterbus_frontend.kicad_sch]
2026-08-23 sch: replace input caps with electrolytic
    [psu.kicad_sch]
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2026-08-23 pcb(eth): fix some drc errors
    [EveningStar.kicad_pcb, ethernet.kicad_sch]
2026-09-04 pcb(psu): layout dc-dc converter
    [EveningStar.kicad_pcb, psu.kicad_sch]
2026-09-04 pcb(mcu): route most of the esp
    [EveningStar.kicad_pcb, mcu.kicad_sch, usb.kicad_sch]
2026-09-06 pcb: route remaining tracks
    [EveningStar.kicad_pcb, flash.kicad_sch, mcu.kicad_sch]
2026-09-06 pcb: fix most drc errors
    [EveningStar.kicad_pcb, flash.kicad_sch, mcu.kicad_sch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]
2026-09-06 pcb: move assembly mounts, led and silkscreen logo
    [EveningStar.kicad_pcb]
2026-09-06 pcb: add some silkscreen graphics
    [EveningStar.kicad_pcb]
2026-09-06 pcb: add sn location
    Fixed #14
    Specifies JLCPCB serial number location with silkscreen rectangle
    [EveningStar.kicad_pcb]
2026-09-06 pcb(silkscreen): add logo and move silkscreen items
    [EveningStar.kicad_pcb]
2026-09-21 pcb(3d_models): fixes 3d model path for capacitor
2026-09-21 pcb(silkscreen): fix power socket silkscreen clipping
    [EveningStar.kicad_pcb, psu.kicad_sch]
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2026-09-21 pcb(footprints): fix footprint locality
    [EveningStar.kicad_pcb, ethernet.kicad_sch, mcu.kicad_sch]
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2026-09-21 docs: add product summary to the README
    Describe the V2 board as a product: specifications, the protection it
    has, and how to install it. Each rating and protection was checked
    against the schematic netlist or the component datasheets.
    The installation section asks for a 1 A fuse near the power source and
    wiring rated for at least 1 A, and warns against leaving USB connected
    in service, because USB ground is tied directly to the power input's
    negative terminal and would give return current an unfused path.
    The intro no longer claims the isolation protects USB equipment, since
    only the MeterBus side is isolated. Links to the latest release and the
    JLCPCB ordering guide are grouped under a n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
2026-09-21 docs: add a debugging section to the README
    Explain that USB-C goes straight to the ESP32-C6's native USB, whose
    built-in Serial/JTAG controller gives a console, flashing, and JTAG
    debugging, and works on a blank module because the ROM bootloader
    supports it. Firmware can still disable it, so describe recovering
    through the debug header's BOOT and RST pins.
    Document the debug header's pinout from the netlist and when to remove
    the J_3V3 and J_RST jumpers: J_3V3 stops a programmer's 3.3 V from
    backfeeding the converter when the board runs from its DC input, and
    J_RST stops the converter's power-good signal from holding reset low.
    The header is described by its pins rather than as an ESP-Pro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
2026-11-06 docs: fix meterbus observations links and bus model
    Point the adapter manual, test circuit image, and scope trace folder
    links at their current locations. The images moved from image/ to
    assets/ and the manual link was resolved relative to docs/ twice.
    Links are now relative so they work on GitHub and in local previews.
    Describe the bus idle level as a zener to ground fed through a series
    10k resistor from the supply rail, replacing the earlier assumption of
    a 10k pull-up to a dedicated 7.5V rail. Note that the measured short
    circuit current and LOW levels imply a lower source voltage than the
    supply rail, which is still unresolved.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
